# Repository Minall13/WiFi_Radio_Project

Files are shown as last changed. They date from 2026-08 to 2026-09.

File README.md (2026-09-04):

# Wi-Fi Radio Project

A standalone touchscreen Internet radio built around the ESP32-S3, with a curated UK station library, live programme metadata, custom carrier PCB and a fully 3D-printed enclosure.

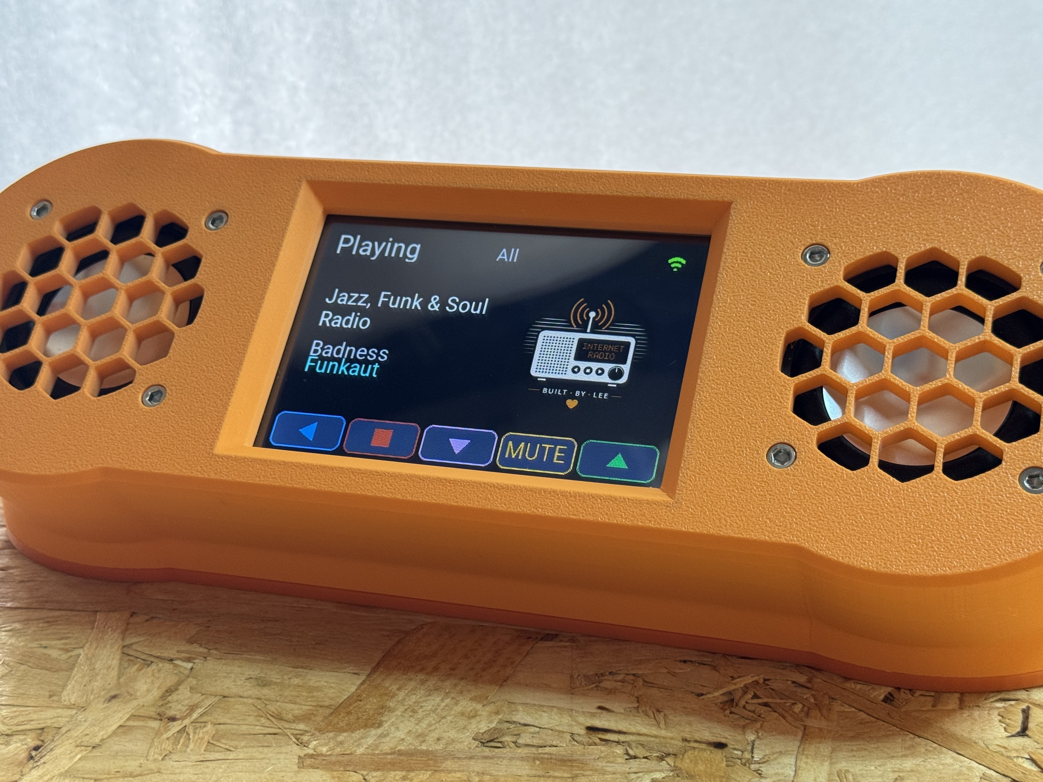
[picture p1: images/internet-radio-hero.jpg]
Wi-Fi Radio Project


The Wi-Fi Radio Project was developed from an initial ESP32 prototype into a complete self-contained radio. The hardware, firmware, user interface, station catalogue, artwork pipeline, PCB and enclosure have all been developed specifically for the project.

The finished radio is designed to behave as an appliance: switch it on, select a station and listen.

---

## Features

- 4-inch 480 × 320 colour touchscreen interface
- ESP32-S3 with 16 MB Flash and 8 MB PSRAM
- Curated UK Internet radio station library
- BBC and commercial radio support
- Live ICY track metadata
- BBC programme metadata
- Station artwork
- Dual-mono audio using two MAX98357A I²S amplifier modules
- Two 3 W / 4 Ω speakers
- Custom carrier PCB
- USB-C power and firmware programming
- Wi-Fi configuration
- Local station catalogue and artwork stored in LittleFS
- Automatic Station Library Builder
- Fully 3D-printable enclosure

---

## User Interface

The radio uses a purpose-built touchscreen interface rather than a generic ESP32 menu system.

Stations are organised into simple groups such as BBC, Absolute, Virgin, Capital, Heart, Kiss, Rock and Talk, with an **All** option providing access to the complete catalogue.

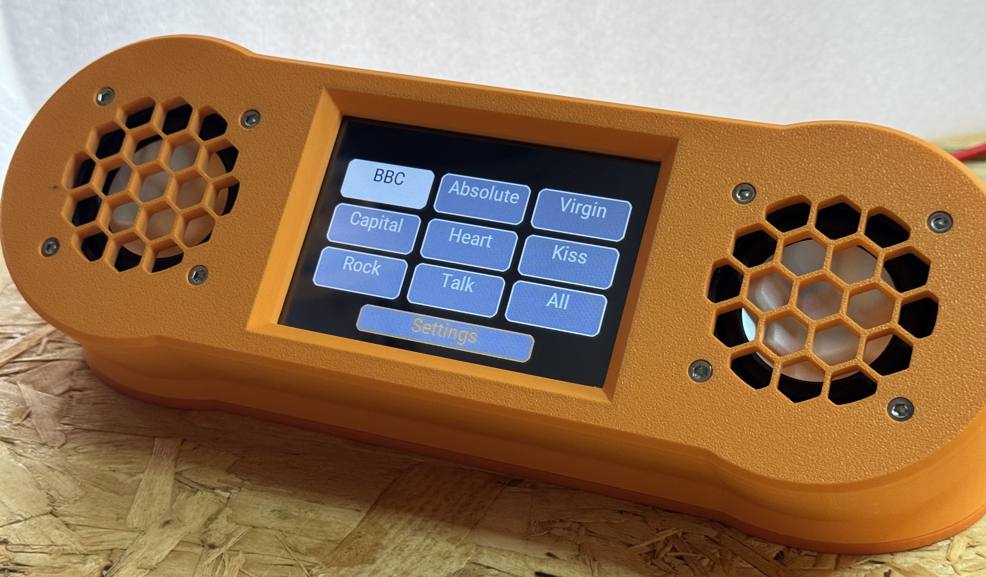
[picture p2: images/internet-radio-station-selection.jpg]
Station selection


The Player screen displays the current station, programme or track information and station artwork, together with controls for navigation, stop, volume and mute.

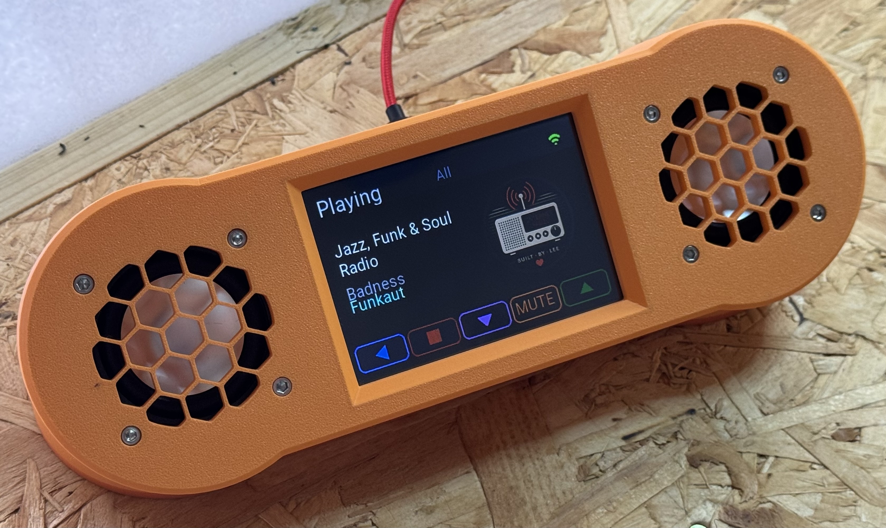
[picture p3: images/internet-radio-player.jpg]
Wi-Fi Radio Player


The startup sequence initialises the filesystem, connects to Wi-Fi, prepares BBC programme information and starts the audio subsystem before presenting the radio for use.

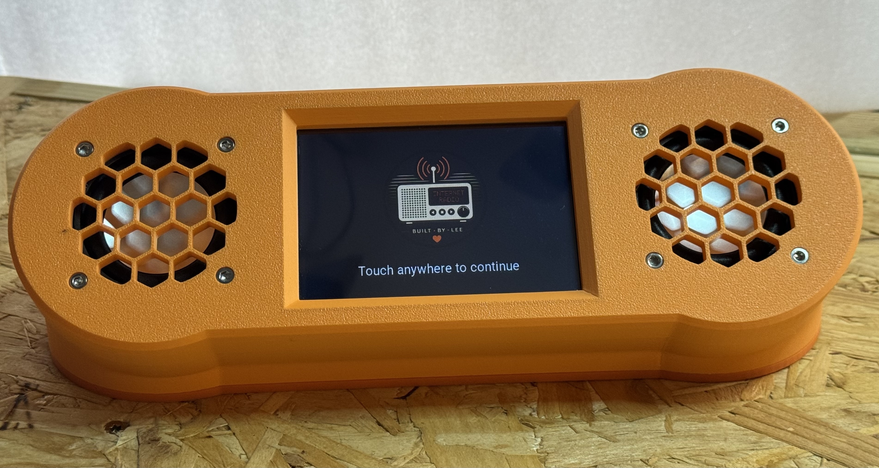
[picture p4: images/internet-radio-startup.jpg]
Wi-Fi Radio startup


---

## Hardware

### Controller

The radio is based around an **ESP32-S3 DevKitC-1 N16R8**:

- 16 MB Flash
- 8 MB PSRAM
- Wi-Fi
- Dual-core ESP32-S3 processor

### Display

- 4-inch 480×320 SPI TFT display, sold as ILI9488 and configured with TFT_eSPI using `ILI9481_DRIVER`
- XPT2046 resistive touchscreen

### Audio

Dual-mono audio is provided by:

- 2 × MAX98357A I²S Class-D amplifier modules
- 2 × 3 W / 4 Ω full-range speakers

### Carrier PCB

A custom KiCad-designed carrier PCB connects the ESP32-S3, display, audio modules, power switching and external USB-C connection.

The PCB was designed specifically for the finished radio and manufactured as part of the project.

The proven Rev A PCB can be ordered directly from the [Wi-Fi Radio Project page on PCBWay](https://www.pcbway.com/project/shareproject/Wi_Fi_Radio_Project_ESP32_S3_Main_PCB_076f3c4a.html).

The rear-panel USB-C connection provides both normal 5 V power and access to the ESP32-S3 USB interface, allowing firmware to be uploaded without dismantling the radio.

PCB design files and manufacturing Gerbers are provided in the `Hardware/` directory.

### Enclosure

The enclosure is fully 3D printed and consists of three principal components:

- Main case
- Face frame
- Base

STL files are provided in this repository for slicer-independent printing.

A Bambu Studio 3MF project, including the complete assembly and individual printable components, is available on [MakerWorld](https://makerworld.com/en/models/3243705-wi-fi-radio-project#profileId-3675408).

The files are located in:

`3D_Files/`

---

## Bill of Materials

A complete parts list for one radio is provided in:

**[BOM.md](BOM.md)**

The BOM includes quantities and example sources for the components used in the original build.

Equivalent components may be used where their electrical and mechanical specifications are compatible.

---

## Software Architecture

The firmware is divided into independent subsystems with clearly defined responsibilities.

```text
Station Library Builder
        │
        ▼
LittleFS Catalogue
        │
        ▼
Station Provider
        │
        ▼
User Interface
        │
        ▼
Player
        │
        ├───────────────┐
        ▼               ▼
Audio Engine     BBC Metadata
        │
        ▼
I²S Audio
        │
        ▼
2 × MAX98357A
```

This separation keeps the user interface, station data, metadata handling and audio playback largely independent of one another.

More detailed design information is available in the `docs/` directory.

---

## Station Library

Rather than querying an Internet radio directory every time the radio starts, the project uses a curated UK station catalogue generated offline.

The **Station Library Builder**:

- validates station definitions;
- selects preferred production streams;
- generates the station catalogues;
- obtains and prepares station artwork;
- generates default artwork where required;
- prepares the files for deployment to LittleFS.

The ESP32 therefore operates from its own local catalogue during normal use.

This makes the radio independent of a live station-directory service while it is operating.

---

## Metadata

Commercial stations primarily use **ICY metadata** supplied by their audio streams.

BBC stations are handled separately using BBC programme metadata, allowing the Player screen to display the programme currently being broadcast.

---

## Station Artwork

Station artwork is stored as PNG images in LittleFS and displayed on the Player screen.

The artwork pipeline can obtain station artwork, apply curated replacements where necessary, generate appropriately sized images and provide default artwork for stations without suitable source material.

> Station names, logos and other third-party branding remain the property of their respective owners. Third-party station artwork is not intended to imply affiliation with or endorsement of this project.

---

## Repository Structure

    WiFi_Radio_Project/
    │
    ├── 3D_Files/                       3D-printable enclosure files
    ├── Hardware/                       KiCad PCB design and manufacturing files
    ├── data/                           Station catalogue and runtime assets
    │   ├── branding/
    │   ├── catalogues/
    │   ├── fonts/
    │   ├── icons/
    │   └── logos/
    ├── docs/                           Project documentation
    ├── images/                         Documentation images
    ├── tools/                          Build and asset-generation utilities
    │   ├── Icon_Builder/
    │   └── Station_Library_Builder/
    │
    ├── WiFi_Radio_Project.ino	        Main Arduino sketch
    ├── partitions.csv                  ESP32 flash partition layout
    ├── deploy                          LittleFS deployment helper
    ├── BOM.md                          Bill of materials
    └── README.md

The remaining numbered `.ino` files in the project root contain the supporting firmware modules.

---

## Building the Radio

The repository contains the principal resources required to reproduce the project:

1. Firmware source
2. Bill of materials
3. KiCad PCB design
4. PCB manufacturing Gerbers
5. 3D-printable enclosure
6. Station Library Builder
7. Supporting documentation

The project was developed and tested using the specific hardware listed in the BOM. Substituting components may require changes to the PCB, enclosure, firmware configuration or pin assignments.

---

## Project Status

**Version 1.0.1**

The Wi-Fi Radio Project has reached its first complete hardware and software release.

The v1.0.1 system includes:

- completed touchscreen user interface;
- curated UK station library;
- streaming audio engine;
- BBC programme metadata;
- ICY metadata;
- station artwork pipeline;
- custom carrier PCB;
- USB-C power and programming;
- dual-mono amplifier and speaker system;
- finished 3D-printed enclosure.

The radio has been assembled and tested as a complete standalone unit.

---

## Documentation

Additional technical documentation is available in the [`docs/`](docs/) directory, covering subjects including:

- system architecture;
- audio;
- display;
- touchscreen;
- operation;
- station catalogue generation;
- artwork and fonts;
- hardware design;
- project history.

---

## Third-Party Components and Services

This project uses a number of third-party open-source libraries, hardware modules and Internet services.

Radio station names and trademarks belong to their respective owners.

Availability and format of Internet radio streams and external metadata services can change independently of this project.

---

## Licence

The Wi-Fi Radio Project uses a mixed licensing model.

Original project software is licensed under the **PolyForm Noncommercial License 1.0.0**.

Original hardware designs, PCB files, 3D-printable models, documentation and project photographs are licensed under the **Creative Commons Attribution-NonCommercial 4.0 International (CC BY-NC 4.0)** licence.

These licences permit personal, non-commercial use, modification and redistribution subject to their respective terms and attribution requirements. Commercial use of the original project material is not permitted without separate permission from the copyright holder.

Third-party components and assets remain subject to their own licences.

See [`LICENSE.md`](LICENSE.md) for the complete licensing details and attribution requirements.

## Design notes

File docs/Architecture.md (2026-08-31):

# Wi-Fi Radio Project — Architecture

## Overview

The Wi-Fi Radio Project firmware is organised as a modular ESP32-S3 application.

Functionality is divided across Arduino `.ino` tabs, with each tab responsible for a specific area of the system. The source files contain their own detailed header documentation; this document therefore describes the overall architecture and the relationships between the major parts of the application.

The principal design goal is to keep the user interface, station catalogue, audio playback and metadata systems independent of one another.

---

## High-Level Architecture

The application can be viewed as four main functional areas:

```text
User Interface / Touch
        │
        ▼
Station Provider
        │
        ├──────────────► Station Artwork
        │
        ▼
Audio Engine
        │
        ├──────────────► ICY Metadata
        │
        └──────────────► BBC Programme Metadata
```

Supporting modules provide Wi-Fi management, themes, typography, icons, startup behaviour and system information.

This separation allows individual parts of the radio to be changed without requiring corresponding changes throughout the application.

---

## Station Catalogue

Normal radio operation uses locally stored station catalogues held in LittleFS.

The catalogues are generated offline by the Python **Station Library Builder** and contain the information required by the firmware to present and play the curated station library.

The Station Provider acts as the interface between the user interface and these catalogue files.

This means that normal station browsing does not depend upon live access to an external station-directory service.

Only the catalogue data required at a particular time is loaded, reducing RAM usage on the ESP32-S3.

---

## Playback Model

Station browsing and station playback are deliberately treated as separate operations.

The application maintains independent state for:

- the currently selected station;
- the currently playing station;
- the current playback state.

This distinction allows the user to leave the Player screen and browse the Station List while the current station continues playing.

Consequently:

```text
Player → Back → Station List
```

preserves playback, whereas:

```text
Player → Stop → Filter Selection
```

terminates playback and returns to the beginning of the normal station-selection flow.

This behaviour is intentional and forms part of the application's navigation model.

---

## Audio

Audio streaming is handled independently by the Audio Engine.

The engine is responsible for:

- stream connection and playback;
- I²S audio output;
- volume control;
- mute state;
- playback status;
- stream metadata handling.

Audio is output through two MAX98357A I²S amplifier modules driving two speakers in a dual-mono configuration.

Keeping audio processing separate from the user interface allows playback to continue while other screens are displayed.

---

## Metadata

The project uses two separate metadata mechanisms.

### ICY Metadata

Commercial internet-radio streams may provide ICY metadata as part of the audio stream.

Where available, this information is used to display the current artist and track on the Player screen.

### BBC Programme Metadata

BBC stations use a separate metadata mechanism to obtain current programme information.

This information is handled independently from the audio stream and presented through the same Player interface.

Separating the two mechanisms allows the user interface to present consistent programme information despite the different metadata sources.

---

## Local Assets

LittleFS provides the radio's local runtime asset storage.

It contains resources including:

- station catalogues;
- station artwork;
- fonts;
- icons.

Keeping these resources locally provides predictable UI performance and avoids unnecessary network dependencies during normal navigation.

The project's custom flash partition configuration and LittleFS deployment process are documented separately in `Build_and_Deploy.md`.

---

## Design Principles

The firmware architecture follows a small number of deliberate principles:

- each module should have a clearly defined responsibility;
- UI rendering should remain separate from audio playback;
- navigation should not unnecessarily interrupt playback;
- station catalogue access should be abstracted from the UI;
- external metadata services should not control core navigation;
- runtime assets should be stored locally where practical;
- common visual behaviour should be controlled through shared theme, typography and icon systems.

The result is a firmware structure in which the major subsystems can be maintained independently while presenting a single consistent interface to the user.

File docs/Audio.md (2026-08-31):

# Wi-Fi Radio Project — Audio

## Overview

The Wi-Fi Radio Project provides Internet radio playback using the ESP32-S3, the ESP32-audioI2S library and two MAX98357A I²S amplifier modules.

The audio subsystem supports the stream formats used by the curated station library, including MP3, AAC/AAC+, HTTP, HTTPS and BBC HLS streams.

Audio processing is intentionally isolated from the user interface and station catalogue.

---

## Hardware

### Controller

ESP32-S3 N16R8

### Amplifiers

2 × MAX98357A I²S Class-D amplifier modules.

Both amplifiers receive the same I²S audio data and drive separate speakers, providing a dual-mono output.

### Speakers

2 × 3 W, 4 Ω speakers.

---

## I²S Configuration

| Signal | GPIO |
|---|---|
| BCLK | GPIO6 |
| LRCK | GPIO7 |
| DOUT | GPIO5 |

The two MAX98357A modules share the I²S signals.

The known working module configuration is:

| Pin | Connection |
|-----|---|
| VIN | 5 V |
| GND | GND |
| DIN | GPIO5 |
| BCLK | GPIO6 |
| LRC | GPIO7 |
| SD | 3.3 V |
| GAIN | Floating |

---

## Audio Library

The project uses **ESP32-audioI2S**.

The library is wrapped by the project's Audio Engine rather than being accessed directly by the user interface.

The principal interface includes:

```cpp
audioBegin()
audioPlay()
audioStop()
audioLoop()
audioSetVolume()
audioGetVolume()
```

This abstraction keeps playback implementation separate from UI and station-catalogue logic.

---

## Volume and Mute

The normal default volume is:

```text
14
```

This provides clean playback with the amplifier and speaker combination used in the finished radio.

Mute is implemented as a latching control. Muting silences the output without terminating the active stream, allowing playback to resume immediately when mute is released.

---

## DMA Configuration

An important optimisation made during development concerns the audio DMA configuration.

HTTPS connection failures were traced to **internal RAM pressure**, rather than to TLS itself.

The ESP32-audioI2S default DMA configuration allocated more internal memory than this application required.

The project therefore uses:

```cpp
audio.settings.DMA_DESC_NUM = 16;
```

rather than the library default of 32 descriptors.

This change:

- increases available internal heap;
- increases the largest available internal memory block;
- improves reliability when establishing HTTPS streams;
- leaves sufficient memory for metadata operations during playback;
- produces no observable reduction in playback quality.

This setting forms part of the project's known working audio configuration.

---

## Main Loop Requirements

The audio library requires:

```cpp
audioLoop();
```

to be serviced frequently.

Long blocking operations can result in buffer underruns, interrupted audio, slower reconnects or delayed metadata processing.

During development, a long main-loop delay was found to cause periodic audio pulsing. Reducing the delay to approximately 1 ms restored stable playback.

Code added to the main application loop should therefore avoid unnecessary blocking operations.

---

## Metadata

### Commercial Stations

Where supported by the station stream, ICY metadata provides current artist and track information.

Metadata updates are handled without requiring the complete Player screen to be redrawn.

### BBC Stations

BBC programme information is obtained separately from the audio stream through the project's BBC metadata subsystem.

This allows current BBC programme information to be presented through the Player interface even though it is supplied through a different mechanism from commercial ICY metadata.

---

## Playback Behaviour

The Audio Engine maintains playback independently from screen navigation.

This allows the current stream to continue when the user selects **Back** from the Player and returns to the Station List.

Selecting **Stop** explicitly terminates the current stream.

Volume and mute operations alter the audio output without changing the selected station or navigation state.

---

## Design Constraints

Changes to the audio subsystem should preserve the following known working characteristics:

- I²S on GPIO5, GPIO6 and GPIO7;
- dual-mono MAX98357A output;
- frequent servicing of `audioLoop()`;
- minimal blocking activity during playback;
- reduced DMA descriptor allocation;
- sufficient internal RAM for HTTPS connections and metadata operations.

These constraints were established through testing and form part of the stable v1.0 audio implementation.

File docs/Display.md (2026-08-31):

# Display Hardware Notes

## Hardware

Display: 4" SPI TFT Touch Display

Touch Controller: XPT2046

Controller advertised by seller: ILI9488

Board used: ESP32-S3 N16R8

---

## TFT_eSPI Configuration

Working TFT_eSPI setup:

```cpp
#define USE_HSPI_PORT

#define ILI9481_DRIVER

#define TFT_MISO 13
#define TFT_MOSI 11
#define TFT_SCLK 12
#define TFT_CS   10
#define TFT_DC    9
#define TFT_RST   8
```

---

## Important Discovery

Although the display was advertised and silk-screened as an ILI9488 display, it would not operate correctly using:

```cpp
#define ILI9488_DRIVER
```

The display only operated correctly when configured as:

```cpp
#define ILI9481_DRIVER
```

This should be considered the known-good configuration for this display module.

---

## Touchscreen Discovery

For the XPT2046 touchscreen to function correctly:

```text
TFT SDO (MISO) must be disconnected
```

Working touch wiring:

```text
T_DO  -> GPIO13
T_DIN -> GPIO11
T_CLK -> GPIO12
T_CS  -> GPIO14
T_IRQ -> Not connected
```

If TFT SDO remains connected to GPIO13, the touchscreen reports:

```text
Touched = YES | X = 0 | Y = 0 | Z = 4095
```

continuously and does not respond to touch input.

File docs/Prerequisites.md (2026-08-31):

# Prerequisites

This document describes the software and development tools required to build, deploy, inspect and modify the Wi-Fi Radio Project.

Not every tool listed here is required for every task. The minimum requirements depend on whether you are:

- building and uploading the firmware;
- rebuilding the station catalogue and artwork;
- regenerating display fonts;
- modifying the PCB;
- modifying or printing the enclosure.

---

## 1. Arduino Development

### Arduino IDE

The firmware is developed and uploaded using **Arduino IDE**.

Install the current Arduino IDE from the official Arduino website.

### ESP32 Board Support

Install the **ESP32 Arduino board package** through Arduino IDE.

The project hardware uses an:

**ESP32-S3 DevKitC-1 N16R8**

with:

- 16 MB Flash;
- 8 MB PSRAM.

When compiling the project, ensure that the selected board and Flash/PSRAM settings are appropriate for the N16R8 module.

The project also uses the custom root-level `partitions.csv`, which provides approximately:

- 3 MB application space;
- 12.9 MB LittleFS space;
- no OTA application partition.

Further build and upload instructions are provided in `docs/Build_and_Deploy.md`.

---

## 2. Arduino Libraries

The finished firmware uses the following libraries:

- ArduinoJson
- ESP32-audioI2S (`Audio.h`)
- HTTPClient
- LittleFS
- PNGdec
- TFT_eSPI
- WiFi
- WiFiClientSecure
- WiFiManager
- XPT2046_Touchscreen

The following are provided as part of the ESP32 Arduino environment rather than installed as separate third-party libraries:

- SPI
- WiFi
- WiFiClientSecure
- HTTPClient
- LittleFS
- `esp_heap_caps.h`

Where a library version is important to project behaviour, use the version documented with the project.

The audio implementation was developed and validated using:

**ESP32-audioI2S 3.4.6**

---

## 3. Python

The Station Library Builder is written in Python.

Install a current **Python 3** release.

The Station Library Builder requires the Pillow Python package. It must be installed in the project's virtual environment before any Station Library Builder command can be run.

The recommended project setup is to use a Python virtual environment in the repository root.

Create the environment with:

`python3 -m venv .venv`

Activate it on macOS or Linux with:

`source .venv/bin/activate`

The Station Library Builder uses Python standard-library modules together with one external package:

**Pillow**

Install Pillow with:

`python -m pip install Pillow`

The Station Library Builder can then be run using:

`./.venv/bin/python tools/Station_Library_Builder/station_catalogue_manager.py build`

Detailed station catalogue and artwork information is provided in `docs/Station_Artwork.md`.

---

## 4. Processing IDE

The display uses TFT_eSPI Smooth Fonts stored as `.vlw` files.

To regenerate or modify these fonts, install:

**Processing IDE**

The font-generation workflow uses the TFT_eSPI Smooth Font generator, normally based on `Create_font.pde`.

The project uses the Google Roboto SemiCondensed font family.

The current generated font assets are stored in `data/fonts/`.

Detailed font-generation information is provided in `docs/FontGeneration.md`.

Processing is not required merely to compile or upload the existing firmware if the supplied `.vlw` files are retained.

---

## 5. Source-Code Editor

A separate source-code editor is optional.

The project can be edited entirely using Arduino IDE, but a general-purpose editor may be more convenient for:

- Python;
- JSON;
- Markdown documentation;
- repository-wide searches;
- project maintenance.

The project was developed using tools including **Visual Studio Code** and **BBEdit**, but neither is a mandatory dependency.

---

## 6. Git

Git is recommended when cloning or maintaining the project repository.

Typical uses include:

- downloading the source;
- tracking local modifications;
- updating from GitHub;
- maintaining personal branches or forks.

Git is not required simply to copy the source files and build the project manually.

---

## 7. KiCad

The custom carrier PCB was designed using:

**KiCad 10**

Install KiCad if you want to:

- inspect the schematic;
- inspect or modify the PCB;
- regenerate manufacturing files;
- create a revised board design.

The authoritative hardware design files are stored in `Hardware/`.

KiCad is not required to build firmware for an already assembled radio.

---

## 8. 3D Printing and CAD

The enclosure consists of three printable components:

- Base;
- Main Case;
- Face Frame.

Generic STL files are provided for use with compatible slicers and printers.

The supported Bambu-oriented print package is published separately through MakerWorld.

For Bambu printers, **Bambu Studio** or the Bambu Handy / MakerWorld workflow can be used.

Other slicers may be used with the supplied STL files.

A CAD application is only required if the enclosure geometry is to be modified.

---

## 9. USB Connection

Firmware can be uploaded directly to the ESP32-S3 through USB.

The finished radio provides rear USB-C access so firmware can be updated without disassembling the enclosure.

Before uploading firmware or LittleFS data:

- close Arduino Serial Monitor;
- close any other application using the ESP32 USB/serial port;
- confirm the correct USB device is selected.

---

## 10. Minimum Setup by Task

### Firmware only

Required:

- Arduino IDE;
- ESP32 Arduino board support;
- required Arduino libraries;
- USB connection to the ESP32-S3.

### Rebuild station catalogue and artwork

Additionally required:

- Python 3;
- Python virtual environment;
- Pillow.

### Regenerate fonts

Additionally required:

- Processing IDE;
- TFT_eSPI Smooth Font generator;
- required font family.

### Modify PCB

Additionally required:

- KiCad 10 or a compatible later version.

### Print enclosure

Required:

- suitable slicer or MakerWorld/Bambu workflow;
- compatible 3D printer.

---

## 11. Next Step

Once the required tools are installed, continue with `docs/Build_and_Deploy.md`.

For station catalogue and artwork preparation, see `docs/Station_Artwork.md`.

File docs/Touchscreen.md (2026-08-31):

# Touchscreen Hardware Notes

## Hardware

Touch Controller: XPT2046

Display Module: 4" SPI TFT Touch Display

Processor: ESP32-S3 N16R8

---

## Working Wiring

| Touch Pin | ESP32-S3 Pin  |
| --- | --- |
| T_DO | GPIO13 |
| T_DIN | GPIO11 |
| T_CLK | GPIO12 |
| T_CS | GPIO14 |
| T_IRQ | Not connected |

---

## Critical Discovery

The TFT and touch controller cannot both drive GPIO13.

The TFT SDO(MISO) connection must be disconnected.

```text
TFT SDO(MISO) = Not Connected
Touch T_DO    = GPIO13
```

If TFT SDO remains connected:

```text
Touched = YES | X = 0 | Y = 0 | Z = 4095
```

is reported continuously and the touch screen does not respond.

---

## Calibration Values

```cpp
#define TOUCH_MIN_X 300
#define TOUCH_MAX_X 3820
#define TOUCH_MIN_Y 420
#define TOUCH_MAX_Y 3770
```

---

## Coordinate Mapping

Landscape orientation:

```cpp
int screenX = map(p.x, TOUCH_MIN_X, TOUCH_MAX_X, 0, 480);
int screenY = map(p.y, TOUCH_MIN_Y, TOUCH_MAX_Y, 0, 320);
```

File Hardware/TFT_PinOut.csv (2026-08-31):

ESP32-S3 |  | TFT
* |  | 1 | T_IRQ
13 | ___________ | 2 | T_DO
11 | ___________ | 3 | T_DIN
14 | ___________ | 4 | T_CS
12 | ___________ | 5 | T_CLK
* |  | 6 | SDO (MISO)
3V3 | ___________ | 7 | LED
12 | ___________ | 8 | SCK
11 | ___________ | 9 | SDI (MOSI)
9 | ___________ | 10 | DC/RS
8 | ___________ | 11 | RESET
10 | ___________ | 12 | CS
GND | ___________ | 13 | GND
3V3 | ___________ | 14 | VCC

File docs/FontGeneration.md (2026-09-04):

# Font Generation

## Purpose

This project uses TFT_eSPI Smooth Fonts (`.vlw`) to provide a clean, professional typography system for the Internet Radio user interface.

The generated font files are stored in:

```text
/data/fonts/
```

---

## Font Family

Google Roboto SemiCondensed

---

## Font Generator

The `.vlw` fonts were generated using:

- Processing IDE
- TFT_eSPI `Create_font.pde`

The TFT_eSPI font-generation utility can be found within the installed TFT_eSPI library under:

```text
Tools/Create_Smooth_Font/Create_font/
```

---

## Project Font Set

The Smooth Font files currently stored with the project are:

| File | Size |
|---|-----:|
| Roboto24.vlw | 24 pt |
| Roboto28.vlw | 28 pt |
| Roboto32.vlw | 32 pt |
| Roboto36.vlw | 36 pt |
| Roboto38.vlw | 38 pt |
| Roboto40.vlw | 40 pt |

The active typography mappings are defined in `08_UI_Typography.ino`.
`Roboto38.vlw` is retained in the font set but is not currently assigned to a UI typography role.

The font files are stored in:

```text
/data/fonts/
```

---

## Processing Settings

For each font generated:

* `fontType = ""`
* `fontSize = required size`
* `displayFontSize = same as fontSize`
* Unicode Block:

  * Basic Latin (`0x0021`–`0x007E`)
* Anti-aliased:

  * Enabled

The generated `.vlw` file is copied into:

```text
/data/fonts/
```

and renamed using the project's standard naming convention.

---

## Design Principle

Application code should never reference a specific font family.

All text rendering is performed through the Typography module (`08_UI_Typography.ino`) using semantic roles such as:

* Header
* Section
* Body
* Button
* Caption
* Status
* Display

This allows the font family, weight and point size to be changed in one location without modifying the application UI.

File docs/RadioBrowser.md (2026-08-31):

# Radio Browser

## Purpose

Radio Browser provides the source data used to build the Internet Radio station catalogue.

It is **not** used during normal operation of the radio.

Instead, the Python **Station Library Builder** processes, validates and prepares station data before generating the production catalogue stored in LittleFS.
---

## Current Workflow

```text
Radio Browser API
        │
        ▼
Station Library Builder (Python)
        │
        ▼
station_library.json
        │
        ▼
Paged catalogue files
(catalogues/*.json)
        │
        ▼
LittleFS Image
        │
        ▼
ESP32 Internet Radio
```

---

## Responsibilities

### Radio Browser

- Provides UK station metadata
- Provides stream URLs
- Provides station tags and codec information
- Provides station logos (where available)

### Wi-Fi Radio Project

- Selects supported UK stations
- Removes duplicate entries
- Builds production catalogue files
- Stores the catalogue in LittleFS
- Loads catalogue pages during runtime

---

## Runtime Behaviour

During normal operation the ESP32 **never queries Radio Browser**.

Station browsing is performed entirely from the locally stored catalogue.

This provides:

- Faster station browsing
- Reduced network traffic
- Consistent station ordering
- Offline browsing capability (network required only for audio streaming)

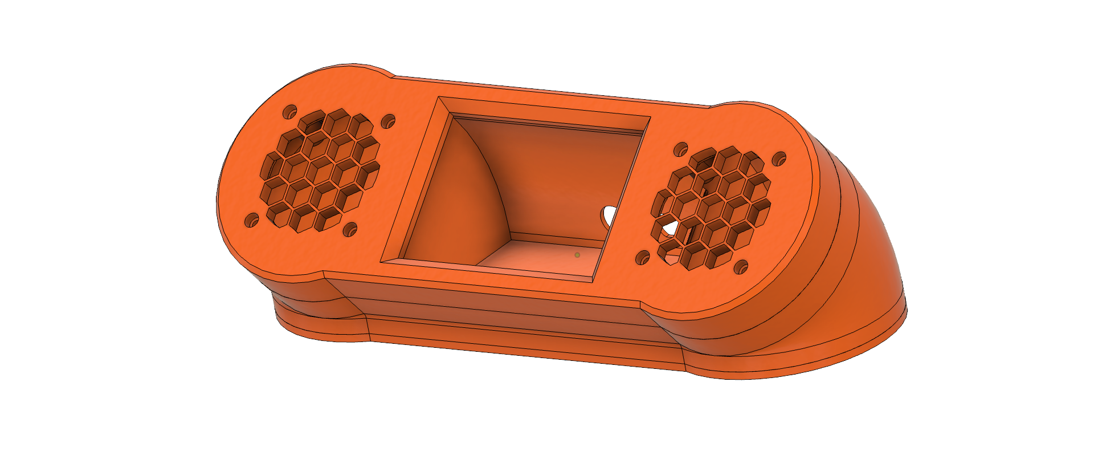
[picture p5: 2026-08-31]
3D_Files/Wi-Fi Radio Project Render.png

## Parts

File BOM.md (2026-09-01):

# Wi-Fi Radio Project — Bill of Materials

This document lists the principal components used to build the Wi-Fi Radio Project.

The links below are provided as examples of the components used in the original build. Equivalent parts may be substituted where their electrical and mechanical specifications are compatible.

> **Note:** Retail links may change or become unavailable over time. The project is not affiliated with or endorsed by the listed retailers or manufacturers.

## Main Components

| Ref | Qty | Component | Example Source |
| --- | ---: | --- | --- |
| IRP001 | 1 | ESP32-S3 DevKitC-1 N16R8 Module | [Amazon UK](https://amzn.eu/d/0hGKXkMX) |
| IRP002 | 1 | 4 inch LCD TFT touch display | [Amazon UK](https://amzn.eu/d/0cEZjH7h) |
| IRP003 | 2 | MAX98357A I²S 3 W Class-D Audio Amplifier Module | [Amazon UK](https://amzn.eu/d/02SEZ3c8) |
| IRP004 | 2 | 2" 4 Ohm 3 W Full Range Audio Speaker Stereo Woofer Loudspeaker | [Amazon UK](https://amzn.eu/d/07zwBBQc) |
| IRP005 | 1 | USB Type-C Screw Panel Mount to 6-pin JST-PH Cable | [Amazon UK](https://amzn.eu/d/0ejVC6VA) |
| IRP006 | 1 | USB-C to XH2.54 4-pin Terminal Motherboard Power Supply Cable | [Amazon UK](https://amzn.eu/d/01NWOgeu) |
| IRP007 | 1 | Ultra Slim Flat USB-C Type-C Male to Female Extension Data Cable, 90° | [Amazon UK](https://amzn.eu/d/021Mz2hg) |
| IRP008 | 1 | Push Button SPST Latching Switch | [Amazon UK](https://amzn.eu/d/03VBz3cK) |
| IRP009 | 4 | M3 (3 mm × 20 mm) Allen Socket Cap Head Screws | [Amazon UK](https://amzn.eu/d/0aBU8Lml) |
| IRP010 | 8 | M3 (3 mm × 10 mm) Allen Socket Cap Head Screws | [Amazon UK](https://amzn.eu/d/0j475W6z) |
| IRP011 | 12 | M3 Threaded Inserts | [Amazon UK](https://amzn.eu/d/0cYBCU3H) |

## Notes

- Check component dimensions and pinouts before ordering substitutes.
- The PCB and enclosure were designed around the components used in the original build, so mechanically different alternatives may require modification.
- Quantities shown are for one complete Wi-Fi Radio Project unit.

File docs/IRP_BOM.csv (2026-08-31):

Part No. | Quantity | Item | Item Link (Amazon)
IRP001 | 1 | ESP32-S3 DevKitC-1 N16R8 Module | https://amzn.eu/d/0hGKXkMX
IRP002 | 1 | 4 inch LCD TFT touch display | https://amzn.eu/d/0cEZjH7h
IRP003 | 2 | MAX98357 Class D Audio Amplifier Board I2S 3W DAC Decoder Breakout Module | https://amzn.eu/d/02SEZ3c8
IRP004 | 2 | 2" 4Ohm 3W Full Range Audio Speaker Stereo Woofer Loudspeaker | https://amzn.eu/d/07zwBBQc
IRP005 | 1 | USB Type C Screw Panel Mount to 6 pin JST PH Cable | https://amzn.eu/d/0ejVC6VA
IRP006 | 1 | USB-C to XH2.54 4Pin Terminal Motherboard Power Supply Cable | https://amzn.eu/d/01NWOgeu
IRP007 | 1 | Ultra Slim Flat USB-C Type-C Male to Female Extension Data Cable 90 Deg. | https://amzn.eu/d/021Mz2hg
IRP008 | 1 | Push Button SPST Latching Switch | https://amzn.eu/d/03VBz3cK
IRP009 | 4 | M3 (3mm x 20mm) Allen Socket Cap Head Screws (x4) | https://amzn.eu/d/0aBU8Lml
IRP010 | 8 | M3 (3mm x 10mm) Allen Socket Cap Head Screws (x8) | https://amzn.eu/d/0j475W6z
IRP011 | 12 | M3 Threaded Insert (x12) | https://amzn.eu/d/0cYBCU3H

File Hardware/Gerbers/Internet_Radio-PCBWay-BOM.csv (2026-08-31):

Designator | Quantity | Value | Manufacturer Part Number | Description | Package | Substitution
J2 | 1 | USB PANEL | B6B-PH-K-S | 6-pin vertical JST-PH connector, 2.00 mm pitch | JST PH 1x06 Vertical | Compatible equivalent permitted; identical pin count, pitch and PCB footprint required
J4 | 1 | USB ESP32 | B4B-XH-A | 4-pin vertical JST-XH connector, 2.50 mm pitch | JST XH 1x04 Vertical | Compatible equivalent permitted; identical pin count, pitch and PCB footprint required
J5 | 1 | POWER SW | B2B-XH-A | 2-pin vertical JST-XH connector, 2.50 mm pitch | JST XH 1x02 Vertical | Compatible equivalent permitted; identical pin count, pitch and PCB footprint required
R1 R2 | 2 | 5.1k | Generic | 5.1 kOhm resistor, 1% | 0603 (1608 metric) | Any reputable equivalent permitted

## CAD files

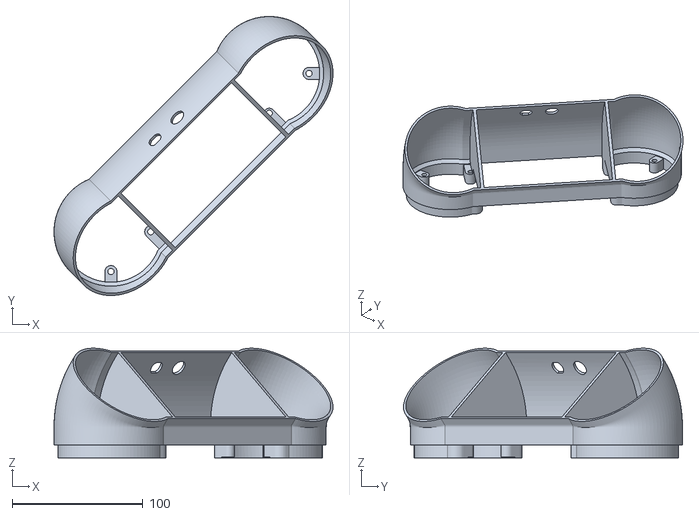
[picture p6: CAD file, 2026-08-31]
3D_Files/WRP_Main_Case.stl
213.1 x 213.1 x 83.7

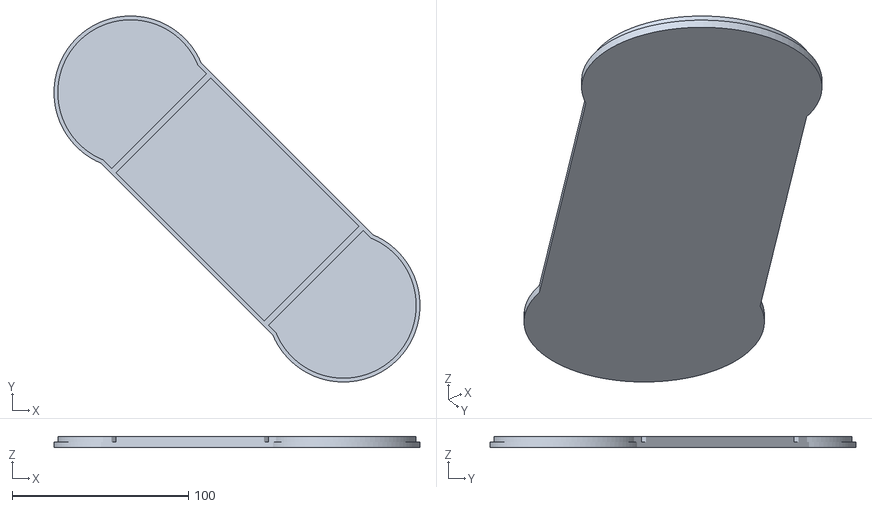
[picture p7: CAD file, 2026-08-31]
3D_Files/WRP_Base.stl
207.9 x 207.9 x 6.00

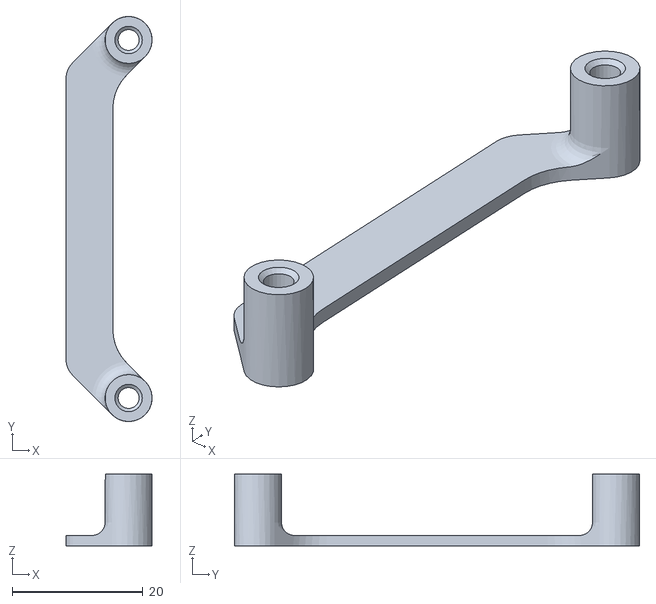
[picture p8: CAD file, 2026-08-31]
3D_Files/WRP_PCB_Stand_Off.stl
13.2 x 62.0 x 11.0

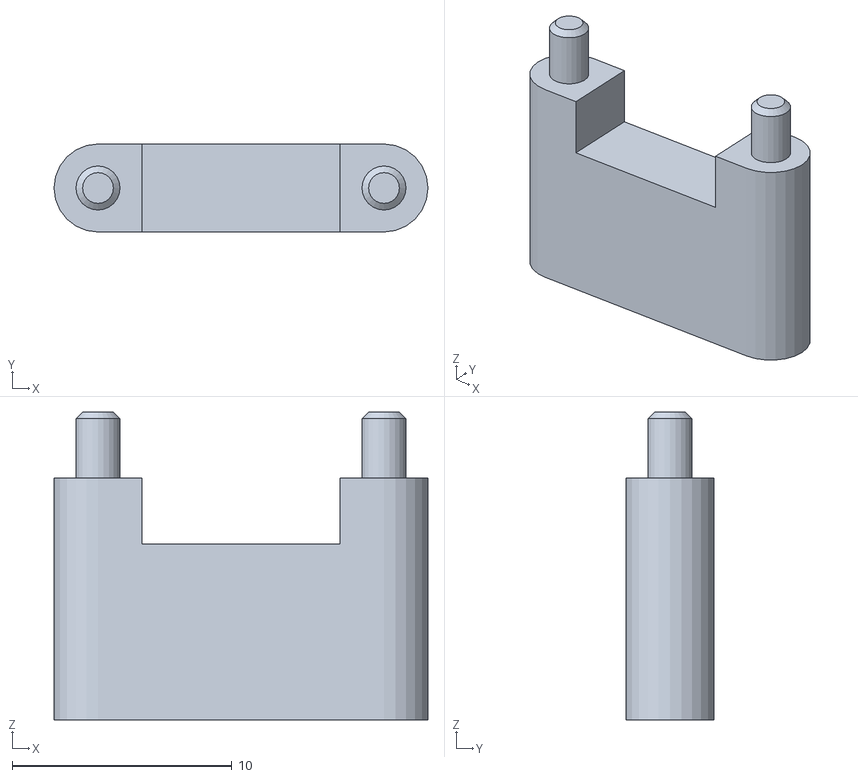
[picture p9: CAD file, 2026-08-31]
3D_Files/WRP_MAX98357A_Stand_Off.stl
17.0 x 4.00 x 14.0

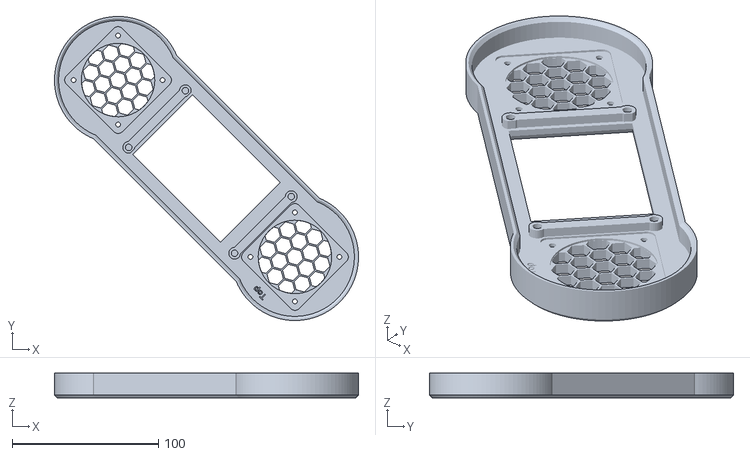
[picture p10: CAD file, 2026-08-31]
3D_Files/WRP_Face_Frame.stl
207.9 x 207.9 x 17.0

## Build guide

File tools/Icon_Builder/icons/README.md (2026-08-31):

# UI Icon Sources

The SVG files in this directory are derived from Google's Material Symbols collection and are used to generate the RAW565 status icons displayed by the Wi-Fi Radio Project.

The project currently uses the following Material Symbols:

- Wi-Fi
- Wi-Fi Off
- Bookmark Stacks
- Import Contacts
- Router
- Router Off

Material Symbols are provided by Google under the Apache License, Version 2.0.

Source:
https://fonts.google.com/icons

Project repository:
https://github.com/google/material-design-icons

Licence:
https://www.apache.org/licenses/LICENSE-2.0

The generated RAW565 files used by the radio are stored in `data/icons/`.

Google and Material Symbols are trademarks or resources of their respective owners. Their inclusion in this project does not imply endorsement of the Wi-Fi Radio Project by Google.

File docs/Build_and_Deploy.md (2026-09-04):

# Internet Radio Project — Build and Deploy

This document describes how to prepare the software, generate the station catalogue, deploy the LittleFS filesystem and upload the firmware to an Internet Radio Project unit.

It assumes that the hardware has already been assembled and that the repository has been downloaded or cloned to the development computer.

---

## 1. Requirements

### Hardware

The original project uses:

- ESP32-S3 DevKitC-1 N16R8;
- 4-inch 480 × 320 TFT display (ILI9488-labelled module, operated using the TFT_eSPI ILI9481 driver);
- XPT2046 resistive touchscreen;
- 2 × MAX98357A I²S amplifier modules;
- 2 × 3 W / 4 Ω speakers;
- Internet Radio Project carrier PCB.

See [`../BOM.md`](../BOM.md) for the complete bill of materials.

### Development Software

The build environment requires:

- Arduino IDE;
- ESP32 Arduino board package;
- Python 3;
- Python packages required by the Station Library Builder;
- `esptool`;
- the Arduino libraries used by the project.

The repository contains the project-specific tools required to build the station catalogue and LittleFS filesystem.

---

## 2. Obtain the Project

Clone or download the repository and open a Terminal in the project root.

The following files and directories should be visible:

```text
WiFi_Radio_Project.ino
data/
docs/
Hardware/
tools/
```

Commands in this document assume that the current Terminal directory is the project root.

Confirm this with:

```bash
pwd
```

---

## 3. Python Environment

The Station Library Builder is written in Python.

The development project uses a virtual environment named:

```text
.venv
```

If an appropriate virtual environment has already been created, the builder can be invoked directly using its Python interpreter:

```bash
./.venv/bin/python tools/Station_Library_Builder/station_catalogue_manager.py
```

Python environment requirements may vary according to platform and local installation.

---

## 4. Station Library Builder

The radio does not query an Internet radio directory during normal operation.

Instead, its station catalogue is prepared offline using the **Station Library Builder**.

From the project root, run:

```bash
./.venv/bin/python tools/Station_Library_Builder/station_catalogue_manager.py build
```

The builder prepares the runtime station data required by the ESP32.

Its tasks include:

1. Loading the source station information.
2. Applying the curated station definitions.
3. Preparing BBC station records.
4. Validating station information.
5. Preparing station artwork where available.
6. Generating filter catalogues.
7. Writing the station library.
8. Preparing the generated files for LittleFS deployment.

Warnings relating to unavailable external artwork do not necessarily indicate that the catalogue build has failed.

A successful build should finish with:

```text
✓ Ready for LittleFS upload.
```

---

## 5. Generated Catalogue Files

Generated runtime files are written beneath:

```text
data/
```

Important files include:

```text
data/station_library.json
data/catalogues/index.json
```

The catalogue directory can be inspected with:

```bash
ls -lh data/catalogues
```

The station catalogue is subsequently stored in the ESP32's LittleFS filesystem.

---

## 6. Station Artwork

The Station Library Builder also prepares artwork used by the Player interface.

Generated artwork is stored in the project's LittleFS data structure and is deployed with the station catalogue.

Station names, trademarks and logos remain the property of their respective owners.

A public distribution of this project may omit third-party station artwork. In that case, artwork should be obtained or generated locally using the Station Library Builder where appropriate.

---

## 7. UI Icon Generation

The Settings screen uses a small set of RAW565 status icons stored in the LittleFS filesystem.

The runtime icons used by the firmware are located in:

    data/icons/

These files can be regenerated from the source SVG artwork using the Processing-based Icon Builder supplied with the project:

    tools/Icon_Builder/

The important source files are:

    tools/Icon_Builder/SVG_to_RAW565.pde
    tools/Icon_Builder/icons/

Open `SVG_to_RAW565.pde` in the Processing IDE and run the sketch to generate the RAW565 icon variants.

Generated files are written to:

    tools/Icon_Builder/output/

The `output/` directory is generated locally and is not required to be stored in the repository.

Copy the required generated icon files into:

    data/icons/

Only the icons actually required by the firmware need to be placed there.

The files in `data/icons/` are subsequently included in the LittleFS image and uploaded to the ESP32-S3 with the rest of the runtime data.

UI icons only need to be regenerated when the icon artwork, size, colour or other graphical properties are changed.

---

## 8. Build LittleFS

The project includes a convenience helper for building and uploading the LittleFS filesystem.

Before starting, close Arduino Serial Monitor and any other application using the ESP32-S3 serial/USB connection.

From the project root, run:

    ./deploy

The root `deploy` helper invokes:

    tools/deploy_littlefs.sh

which performs the LittleFS build and upload process.

The underlying scripts are:

    tools/build_littlefs.sh
    tools/upload_littlefs.sh

The build process creates:

    build/littlefs.bin

The upload process then writes the filesystem image to the ESP32-S3 using `esptool`.

Successful deployment should finish with:

    LittleFS upload complete.

---

## 9. Script Permissions

On macOS or another Unix-like system, the deployment scripts must be executable.

If the shell reports:

```text
permission denied
```

run:

```bash
chmod +x tools/deploy_littlefs.sh \
  tools/build_littlefs.sh \
  tools/upload_littlefs.sh
```

Then retry:

```bash
./tools/deploy_littlefs.sh
```

---

## 10. USB Connection

The finished Internet Radio Project provides external USB-C access to the ESP32-S3.

This connection supports:

- 5 V power;
- USB data;
- firmware programming.

The completed radio can therefore be programmed without dismantling the enclosure.

During development, ensure that no other application is holding the ESP32 USB/serial port open.

---

## 11. Upload the Firmware

Open:

```text
WiFi_Radio_Project.ino
```

in Arduino IDE.

Confirm that:

1. The ESP32-S3 board support package is installed.
2. The correct ESP32-S3 board is selected.
3. The appropriate Flash and PSRAM settings are selected for the N16R8 module.
4. The project uses the custom `partitions.csv` supplied in the repository root. This provides a 3 MB application partition and approximately 12.9 MB for LittleFS.
5. The radio's USB port is selected under **Tools → Port**.

Click **Upload**.

Wait for Arduino IDE to report successful completion.

LittleFS and firmware are separate uploads. Uploading firmware does not normally require rebuilding the station catalogue unless its data has changed.

---

## 12. First Startup

After both LittleFS and firmware have been deployed, reset or power-cycle the radio.

The startup sequence should initialise:

```text
LittleFS
   ↓
Station data
   ↓
Wi-Fi
   ↓
BBC programme cache
   ↓
Audio
   ↓
Touch interface
```

The display reports startup progress.

When initialisation has completed, the radio displays:

```text
Ready
```

followed by:

```text
Touch anywhere to continue
```

---

## 13. Wi-Fi Provisioning

The radio requires a 2.4 GHz Wi-Fi connection.

Saved Wi-Fi credentials are reused automatically.

On a newly programmed ESP32-S3, or when valid credentials are unavailable, use the radio's Wi-Fi provisioning mechanism to select the required network and provide its credentials.

After successful provisioning, the credentials are stored by the ESP32 and normal startup should reconnect automatically.

---

## 14. Functional Test

After deployment, perform a basic functional test.

Confirm that:

1. The startup sequence completes.
2. Wi-Fi connects successfully.
3. Touching the startup screen opens the Filter screen.
4. Station filters open correctly.
5. Station lists display correctly.
6. A BBC station can be selected.
7. BBC programme information appears where available.
8. Audio plays correctly.
9. A commercial station can be selected.
10. ICY metadata appears where supplied by the broadcaster.
11. Station artwork displays correctly.

On the Player screen test:

- **Back**
- **Stop**
- **Volume −**
- **MUTE**
- **Volume +**

Expected navigation behaviour:

```text
Back → Station List
       Audio continues

Stop → Filter
       Audio stops
```

---

## 15. Serial Diagnostics

For development and troubleshooting, Arduino Serial Monitor can be used to observe the radio during startup and playback.

Useful checks include:

- LittleFS mounts successfully;
- catalogue index loads successfully;
- station catalogue pages load correctly;
- Wi-Fi connects;
- BBC metadata caching completes;
- audio initialises;
- selected streams connect;
- no unexpected ESP32 errors are reported.

Close Serial Monitor before attempting another LittleFS upload if it prevents access to the USB port.

---

## 16. Rebuilding the Station Catalogue

Rebuild the catalogue whenever station definitions, stream URLs, filters or artwork sources are changed.

From the project root:

```bash
./.venv/bin/python tools/Station_Library_Builder/station_catalogue_manager.py build
```

Then redeploy LittleFS:

```bash
./tools/deploy_littlefs.sh
```

Restart the radio after deployment.

Firmware does not need to be recompiled solely because catalogue data has changed.

---

## 17. Combined Catalogue and LittleFS Deployment

On a development system using the project's `.venv`, the catalogue build and LittleFS deployment can be chained:

```bash
./.venv/bin/python tools/Station_Library_Builder/station_catalogue_manager.py build && \
./tools/deploy_littlefs.sh
```

The LittleFS deployment will only begin if the Station Library Builder exits successfully.

Firmware upload remains a separate Arduino IDE operation.

---

## 18. Troubleshooting

### LittleFS upload cannot access the ESP32

Close:

- Arduino Serial Monitor;
- other serial terminals;
- applications using the ESP32 USB port.

Then retry the deployment.

### Station does not play

Internet radio stream URLs can change without notice.

Check whether the broadcaster has changed:

- stream URL;
- streaming protocol;
- codec;
- geographic availability.

Update the curated station definition and rebuild the catalogue if necessary.

### Artwork cannot be obtained

Artwork sources can also change or disappear.

The Station Library Builder can use alternative or default artwork where a suitable station image is unavailable.

### Wi-Fi does not connect

If stored credentials are no longer valid, repeat Wi-Fi provisioning using the required network.

---

## 19. Deployment Summary

The complete software deployment process is:

```text
Prepare development environment
          ↓
Build station catalogue
          ↓
Build LittleFS image
          ↓
Upload LittleFS
          ↓
Compile firmware
          ↓
Upload firmware
          ↓
Configure Wi-Fi if required
          ↓
Functional test
```

Once deployment and Wi-Fi configuration are complete, the radio operates as a standalone appliance and does not require the development computer for normal use.

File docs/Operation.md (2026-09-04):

# Wi-Fi Radio Project — Operation

This document describes normal operation of the completed Wi-Fi Radio Project.

The radio is designed to behave as a standalone appliance. Once firmware, station data and Wi-Fi credentials have been configured, no computer or external application is required for normal use.

---

## 1. Powering On

Press the rear power button to switch on the radio.

The startup screen displays progress while the radio initialises its main subsystems.

The normal startup sequence includes:

1. Initialising the local filesystem.
2. Connecting to Wi-Fi.
3. Caching BBC programme information.
4. Initialising the audio system.
5. Loading the station catalogue.

When startup is complete, the display shows:

**Ready**

followed by:

**Touch anywhere to continue**

Touch the screen to enter the radio interface.

---

## 2. Wi-Fi

The radio requires a 2.4 GHz Wi-Fi connection for Internet radio streaming and programme metadata.

Up to three Wi-Fi networks can be stored. At startup, the radio scans for visible saved networks and attempts to connect in most-recently-used order, allowing it to move between familiar locations without requiring Wi-Fi setup each time.

If no saved network is available, the Wi-Fi configuration system opens the InternetRadio-Setup portal so that a network can be selected and its credentials entered. Newly configured networks are added to the saved list and promoted to most-recently-used status.

Once successfully configured, the radio reconnects to the saved network automatically whenever it is switched on.

---

## 3. Station Filters

After the startup screen, the normal listening flow begins at the **Filter** screen.

Stations are organised into groups to make the catalogue easier to navigate.

Available groups include station families and categories such as:

- BBC
- Absolute
- Capital
- Heart
- Kiss
- Rock
- Talk
- Virgin

An **All** option provides access to the complete station catalogue.

Touch a filter to display the stations belonging to that group.

---

## 4. Station List

The Station List displays the stations available within the selected filter.

Touch a station to begin playback.

The radio then opens the **Player** screen and attempts to connect to the selected Internet stream.

Station information and artwork are loaded from the catalogue stored locally in LittleFS.

---

## 5. Player

The Player screen is the main listening interface.

It displays:

- station name;
- station artwork;
- current track information where available;
- BBC programme information where available;
- Wi-Fi status;
- playback controls.

The footer contains five controls:

| Control | Function |
| --- | --- |
| **Back** | Returns to the Station List while the current station continues playing |
| **Stop** | Stops playback and returns to the Filter screen |
| **Volume −** | Reduces playback volume |
| **MUTE** | Toggles latching mute without stopping the stream |
| **Volume +** | Increases playback volume |

---

## 6. Back and Stop Behaviour

**Back** and **Stop** intentionally perform different functions.

### Back

Touching **Back** returns to the current Station List while the audio stream continues playing.

This allows another station to be selected without first stopping the current one.

While a station is playing, the radio automatically returns to the Player screen after 20 seconds without touchscreen activity. Touching the screen resets this inactivity period, allowing the Station List and other screens to be browsed for as long as required.

### Stop

Touching **Stop** ends the current audio stream and returns to the Filter screen.

The Filter screen represents the beginning of the normal listening flow:

```text
Filter
  ↓
Station List
  ↓
Player
```

---

## 7. Volume

Use **Volume −** and **Volume +** to adjust playback level.

The project firmware limits the normal volume range to values suitable for the MAX98357A amplifier modules and speakers used in the original build.

Very high digital gain levels can cause audible distortion and are intentionally avoided.

---

## 8. Mute

**MUTE** is a latching control.

When mute is enabled:

- audio output is silenced;
- the Internet stream continues;
- playback position is not intentionally interrupted.

Touch **MUTE** again to restore the previous listening state.

Mute is therefore different from **Stop**, which terminates the current stream.

---

## 9. Programme and Track Information

The radio supports two principal forms of live metadata.

### Commercial Stations

Where provided by the broadcaster, ICY metadata is extracted from the audio stream and displayed on the Player screen.

This commonly contains artist and track information.

Metadata availability and formatting are controlled by the broadcaster and therefore vary between stations.

### BBC Stations

BBC stations use programme metadata obtained separately from the audio stream.

This allows the Player screen to display the programme currently being broadcast.

---

## 10. Station Artwork

Station artwork is displayed on the Player screen where suitable artwork is available.

Artwork is stored locally in LittleFS rather than downloaded each time a station is selected.

If no suitable artwork is available, the project can use default station artwork generated by the Station Library Builder.

---

## 11. Settings / System Information

The radio includes a system information/settings screen containing information about the running unit and its network connection.

The displayed information includes the current Wi-Fi connection and firmware identification.

Long Wi-Fi SSIDs are shortened on screen to fit the fixed display layout.

---

## 12. Changing Station

There are two normal ways to change station.

### Within the same group

From the Player screen:

1. Touch **Back**.
2. The current station continues playing.
3. Select another station from the Station List.
4. The Player opens for the newly selected station.

### From another group

From the Player screen:

1. Touch **Stop**.
2. Playback ends.
3. The Filter screen opens.
4. Select another filter.
5. Select the required station.

---

## 13. Switching Off

The radio may be switched off using the rear power button.

There is no software shutdown sequence required for normal use.

---

## 14. Internet Stream Availability

Internet radio streams are operated by their respective broadcasters.

A station that previously worked may occasionally become unavailable because of:

- broadcaster maintenance;
- changes to stream URLs;
- geographic restrictions;
- changes to streaming format;
- temporary Internet or server problems.

Such changes can occur independently of the Wi-Fi Radio Project.

The local station catalogue can be rebuilt or updated when station streams change.

---

## 15. Normal Listening Flow

In everyday use, operation is intentionally simple:

```text
Power On
   ↓
Startup
   ↓
Touch to Continue
   ↓
Filter
   ↓
Station List
   ↓
Player
```

From the Player:

```text
Back → Station List
       Audio continues

Stop → Filter
       Audio stops
```

The intention is that normal listening requires no knowledge of the underlying ESP32 firmware, station catalogue or streaming architecture.

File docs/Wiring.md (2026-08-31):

# Hardware Wiring

======================================

## TFT Pin Connections

======================================

| TFT Signal | TFT Pin | ESP32-S3 Pin  | Notes |
| --- | --- | --- | --- |
| VCC | 14 | 3V3 | 3.3V supply |
| GND | 13 | GND | Ground |
| CS | 12 | GPIO10 | TFT Chip Select |
| RESET | 11 | GPIO8 | Hardware Reset |
| DC / RS | 10 | GPIO9 | Data / Command |
| MOSI (SDI) | 9 | GPIO11 | SPI Data Out |
| SCK | 8 | GPIO12 | SPI Clock |
| LED | 7 | 3V3 | Backlight permanently on |
| MISO (SDO) | 6 | Not Connected | Display not read |
| T_CLK | 5 | GPIO12 | Shared SPI Clock |
| T_CS | 4 | GPIO14 | Touch CS |
| T_DIN | 3 | GPIO11 | Shared MOSI |
| T_DO | 2 | GPIO13 | Touch MISO |
| T_IRQ | 1 | Not Connected | Interrupt unused |

======================================

## MAX98357A Pin Connections

======================================

| MAX98357A | ESP32-S3 |
|---|---|
| DIN | GPIO5 |
| BCLK | GPIO6 |
| LRC | GPIO7 |
| VIN | 5V |
| GND | GND |
| SD | Floating |
| GAIN | 3.3V |

> The installed MAX98357A V914 breakout modules require `GAIN` connected
> to 3.3 V. Leaving `GAIN` floating produced no output, and mixed gain
> configurations caused severe distortion. Both amplifiers therefore use
> the same 3.3 V gain connection.

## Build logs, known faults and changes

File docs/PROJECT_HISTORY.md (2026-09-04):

# Project History

## v0.1-display-touch-working

**Date:** 19-Jun-2026

**Git Tag:** `v0.1-display-touch-working`

### Objectives Achieved

* ESP32-S3 N16R8 board verified
* 4" TFT display operational
* XPT2046 touchscreen operational
* GitHub repository established
* SSH authentication configured
* Project documentation structure created
* Prototype test sketches archived

### Key Discoveries

#### Display

Display marketed as ILI9488.

Working TFT_eSPI configuration:

```cpp
#define USE_HSPI_PORT
#define ILI9481_DRIVER
```

Display would not operate correctly using:

```cpp
#define ILI9488_DRIVER
```

#### Touchscreen

Working wiring:

```text
T_DO  -> GPIO13
T_DIN -> GPIO11
T_CLK -> GPIO12
T_CS  -> GPIO14
T_IRQ -> Not connected
```

Critical discovery:

```text
TFT SDO(MISO) disconnected
```

If TFT SDO(MISO) is connected, the touchscreen reports continuously:

```text
Touched = YES | X = 0 | Y = 0 | Z = 4095
```

### Calibration Values

```cpp
#define TOUCH_MIN_X 300
#define TOUCH_MAX_X 3820
#define TOUCH_MIN_Y 420
#define TOUCH_MAX_Y 3770
```

### Test Sketches Archived

* 01_TFT_Colour_Test
* 02_Touch_Raw_Test
* 03_Touch_Calibration_Test

### Status

PASS — Display and touchscreen operational and documented.

---

## v0.2-touch-ui-input-working

**Date:** 20-Jun-2026

**Git Tag:** `v0.2-touch-ui-input-working`

### Objectives Achieved

* Touch coordinate mapping verified
* Stations button detection working
* Settings button detection working
* Repeated touch presses working
* Serial feedback operational

### Results

Verified:

* Touch detection
* Coordinate mapping
* Button hit detection
* Repeated touch presses
* Serial feedback

### Test Sketch Archived

* 04_Touch_UI_Input_Test

### Status

PASS — Touch UI input framework operational.

---

## v0.2.1-touch-ui-display-feedback

**Date:** 20-Jun-2026

**Git Tag:** `v0.2.1-touch-ui-display-feedback`

### Objective

Resolve TFT redraw after touch events whilst maintaining reliable touch input.

### Status

PASS — TFT redraw and touch input operate reliably together.

---

## v0.3.0-wifi-connected-basic

**Date:** 21-Jun-2026

### Status

PASS — Basic Wi‑Fi connectivity operational.

---

## v0.3.1-wifi-manager-portal

**Date:** 21-Jun-2026

### Status

PASS — Complete Wi‑Fi configuration workflow operational.

---

## v0.4-radio-browser-browser-ui

**Date:** 23–24 Jun 2026

### Objectives Achieved

* Radio Browser API integrated
* API server failover implemented
* Live station retrieval verified
* TFT station browser implemented
* Touchscreen page navigation implemented
* Filter-based station browsing implemented
* Station name and stream URL storage implemented
* Screen architecture framework implemented
* Footer station selector framework implemented
* Station visual state framework implemented

### Results

Verified:

* Successful retrieval of UK radio station data from Radio Browser
* API failover between multiple Radio Browser servers
* Storage and display of station names and stream URLs
* Storage of up to 40 stations
* TFT station browser display
* Touchscreen navigation using graphical ▲ and ▼ buttons
* 5 stations per page layout adopted
* Multi-page station browsing with wrap-around navigation
* Direct filter selection screen implemented

### Screen Architecture

Display divided into fixed zones:

```text
Header   50px
Content 190px
Footer   80px
```

This architecture will be retained for all future screens.

### Footer Navigation Framework

Introduced persistent footer layout:

```text
Home  [1] [2] [3] [4] [5]  Settings
```

Design objectives:

* Large touch targets
* No precision text tapping
* Consistent navigation across all screens
* Appliance-style operation

### Station Selection Philosophy

Station lists are numbered locally per page:

Example:

```text
1. Capital Chill
2. Capital Dance
3. Capital FM Birmingham
4. Capital FM AAC
5. Capital XTRA
```

Footer buttons remain:

```text
[1] [2] [3] [4] [5]
```

Page number provides position within the overall result set.

### Button Visual States

Implemented framework for:

#### Available

* Blue outline
* Blue numeral

Current colour:

```cpp
tft.color565(0,90,220)
```

#### Selected

* Green outline
* Green numeral
* Green glow effect

Current implementation uses a simple circular glow.

#### Disabled

* Grey outline
* Grey numeral

Used for unavailable station slots on short final pages.

### Radio Browser Reliability

Observed behaviour:

* Radio Browser servers occasionally return:

  * HTTP -11
  * HTTP -1
  * HTTP 502

API failover successfully recovers by attempting alternative servers.

Future UI versions should present loading and retry progress visually rather than relying on serial output.

### User Interface Direction

Reference UI concept documented in:

```text
docs/UI_Concept_v1.md
images/Internet_Radio_UI_Concept_v1.png
```

Key design goals:

* Clean appliance-style interface
* Persistent navigation
* Consistent visual language
* Large touch targets
* Future anti-aliased typography
* Future Now Playing screen

### Status

PASS — Radio Browser integration validated.

PASS — Station browser architecture established.

PASS — UI framework established.

Audio playback integration can now proceed on a stable foundation.

---

## v0.4.10-footer-selection-logic

**Date:** 26-Jun-2026

**Git Branch:** `v0.4.10-footer-selection-logic`

### Objectives Achieved

* Footer buttons 1–5 now select visible station entries
* Selected station is tracked using `selectedStationIndex`
* Selected footer button remains green
* Previous selected button returns to blue
* Unused station buttons are disabled on short final pages
* Legacy row-touch station selection removed
* Player screen introduced using `SCREEN_PLAYER`
* Station metadata model expanded
* Radio Browser metadata captured and printed for analysis
* Project refactored into multiple Arduino `.ino` tabs
* Project documentation reorganised into `docs/`
* Hardware notes moved into `Hardware/`
* Architecture documentation created

### Station Metadata Added

The `Station` structure now stores:

```cpp
name
streamUrl
resolvedUrl
homepage
favicon
tags
codec
bitrate
isHLS
```

### Screen Architecture

The project now uses a modular screen structure:

```text
Header  = status/context
Content = current task
Footer  = navigation
```

### Arduino Tab Structure

```text
Internet_Radio_Project.ino
01_Debug.ino
02_Display_UI.ino
03_Touch_Input.ino
04_WiFi_Manager.ino
05_RadioBrowser.ino
06_BBC_Stations.ino
07_Player.ino
08_StationProvider.ino
09_UI_Theme_Design.ino
```

### Status

PASS — Footer station selection working.

PASS — Player screen introduced.

PASS — Station metadata storage working.

PASS — Project refactored into maintainable Arduino tabs.

---

## v0.5.0-ui-design-system

**Date:** 27-Jun-2026

**Git Tag:** `v0.5.0`

### Objectives Achieved

* Dynamic Header architecture completed
* Header API (`setHeader()`) implemented
* Header standardised as:

  * Left = Context
  * Centre = State
  * Right = Status
* Filter Grid established as the application landing screen
* Station List and Player screens migrated to the new Header architecture
* Wi-Fi placeholder icon introduced
* First UI Theme framework implemented
* Six colour themes created
* ThemeID framework introduced
* Central Design Guide documented
* Icons module created
* Typography module created
* Project design philosophy documented

### Design System

The project now separates visual design into dedicated modules:

```text
09_UI_Theme_Design.ino
10_UI_Icons.ino
11_UI_Typography.ino
```

This establishes a reusable design system independent of the application logic.

### UI Philosophy

The project now follows the principles:

* Premium appliance, not Arduino demo.
* Typography before decoration.
* Consistent visual hierarchy.
* Header displays context only.
* Footer provides navigation only.
* Content performs the current task.
* Information appears only when it adds value.

### Status

PASS — UI Design System established.

PASS — Theme framework operational.

PASS — Project architecture prepared for production-quality typography and iconography.

## v0.7.0 – UI Polish

### Typography

* [x] Roboto typography system
* [x] Typography roles
* [x] Smooth font integration
* [x] Standard button typography

### Icons and Graphics

* [x] SVG to RAW565 asset pipeline
* [x] Dynamic Wi-Fi icons
* [x] Shared icon framework
* [x] LittleFS icon assets

### User Interface

* [x] Home Dashboard
* [x] Filter screen
* [x] Station List
* [x] Shared header framework
* [x] Theme integration
* [x] Design consistency framework

---

## v0.8.0 – Audio Engine

* [x] MAX98357A I²S amplifier integration
* [x] Reliable audio playback
* [x] Audio abstraction layer
* [x] Playback state management
* [x] Volume control
* [x] Stream recovery
* [x] BBC HLS playback
* [x] Commercial stream playback

---

## v0.8.x – Station Library

### Catalogue Architecture

* [x] Custom ESP32 partition layout
* [x] LittleFS catalogue storage
* [x] Local Station Provider
* [x] Flat paged catalogue format
* [x] Catalogue metadata
* [x] Station Provider abstraction
* [x] Local catalogue browsing

### Station Library Builder

* [x] Curated UK station library
* [x] Production catalogue generation
* [x] Automatic LittleFS deployment
* [x] Build validation
* [x] BBC catalogue provider
* [x] Runtime Radio Browser dependency removed

---

## v0.9.0 – Player Experience

* [x] Dedicated Player footer
* [x] Station artwork
* [x] Default artwork fallback
* [x] PNG artwork pipeline
* [x] Curated artwork overrides
* [x] Rounded station artwork
* [x] Live ICY metadata
* [x] Dynamic metadata updates
* [x] Theme-aware Player typography
* [x] Metadata word wrapping
* [x] Fast station switching

---

## v0.9.1 – Initial BBC Metadata

* [x] Official BBC metadata integration
* [x] BBC RMS metadata client
* [x] National BBC programme metadata
* [x] Player programme display
* [x] Programme end-time storage
* [x] Initial startup cache implementation
* [x] Git milestone tagged (`v0.9.1`)

---

## v0.9.2 – BBC Metadata and HTTPS Stability

### BBC Metadata

* [x] Replace startup cache with on-demand metadata retrieval
* [x] Request metadata only for the selected BBC station
* [x] Delay metadata request until audio playback has started
* [x] Periodic programme metadata refresh
* [x] Active BBC metadata lifecycle management
* [x] Preserve commercial ICY metadata behaviour
* [x] Maintain audio processing during BBC HTTP requests

### Audio and Memory

* [x] Diagnose TLS failures as internal-memory pressure
* [x] Reduce I²S DMA descriptors from 32 to 16
* [x] Restore reliable HTTPS stream connections
* [x] Validate BBC metadata retrieval during active playback
* [x] Add heap diagnostics for metadata and audio testing

### Startup and Repository

* [x] Branded startup splash screen
* [x] Refined startup status sequence
* [x] Package project branding assets
* [x] Package Icon Builder and generated icon assets
* [x] Merge completed milestone into `main`
* [x] Git milestone tagged (`v0.9.2`)

## v0.9.3 – Product Polish

### User Interface

* [x] Review Player layout across representative stations
* [x] Final typography review
* [x] Review alignment, spacing and visual consistency
* [x] Review touch feedback and pressed-state consistency
* [x] Replace remaining hard-coded pressed-state colours with semantic theme colours
* [x] Review screen transitions and redraw behaviour
* [x] Wi-Fi configuration

### System

* [x] Reduce remaining development Serial output
* [x] Retain useful fault and startup diagnostics
* [x] Remove obsolete code and superseded metadata-cache logic
* [x] Final code organisation review
* [x] Documentation review

### Repository

* [x] Review packaged tools for setup instructions
* [x] Review tracked assets for completeness

---

---

## v0.9.4 – Hardware Integration

### Hardware

* Custom carrier PCB designed in KiCad
* ESP32-S3 and dual MAX98357A amplifier modules integrated
* External USB-C power and firmware-upload connection
* Rear-panel power switching
* PCB manufactured and assembled
* Complete hardware validated in the finished unit

### Enclosure

* Three-part enclosure designed for 3D printing
* Separate base, main chassis and face frame
* Dual 2" speaker mounting
* M3 threaded-insert construction
* Rear USB-C and power-button access
* Finished enclosure printed, assembled and validated

### Status

PASS — Custom hardware and enclosure completed.

---

## v1.0.0 – Internet Radio

### Release Milestone

* Firmware feature set completed
* User interface and Player experience completed
* Curated UK station library completed
* BBC and commercial-station metadata operational
* Dual-mono audio system completed
* Custom PCB and enclosure completed
* Final radio assembled and operational
* Build and deployment workflow validated
* Project documentation consolidated
* Git milestone tagged (`v1.0.0`)

### Public Release Preparation

Following completion of v1.0.0, the private development repository was reviewed and consolidated in preparation for a clean public release.

This included:

* Reviewing and consolidating project documentation
* Removing obsolete development notes and diagnostic material
* Reviewing build and deployment instructions
* Reviewing packaged tools and assets
* Preparing the project for publication from a clean repository snapshot

### Status

PASS — Internet Radio v1.0.0 completed and validated.

---

## v1.0.1 – Reliability and Usability Refinement

### Wi-Fi

* Added storage for up to three Wi-Fi networks
* Added visible-network scanning at startup
* Saved networks are attempted in most-recently-used order
* Reduced connection delay when moving between known networks
* Wi-Fi reset now clears both WiFiManager credentials and the saved network list

### Station Catalogue and Streaming

* Changed the All-stations catalogue to load in pages of up to five stations
* Reduced internal heap usage and fragmentation during station browsing
* Improved reliability when connecting to HTTPS/TLS audio streams
* Refreshed the curated station catalogue
* Removed the obsolete talkSPORT 2 stream

### Player

* Refined Player metadata layout and clearing behaviour
* Improved handling of longer artist and track information
* Added automatic return to the Player after 20 seconds of touchscreen inactivity while playback remains active
* Preserved current commercial-station metadata when returning to the Player
* Preserved BBC programme metadata when returning to the Player

### Maintenance

* Removed obsolete RadioBrowser test and debug modules
* Renumbered firmware modules while preserving compilation order
* Retained useful heap, catalogue and audio connection diagnostics
* Corrected display hardware documentation
* Updated Wi-Fi, Player and typography documentation

### Status

PASS — v1.0.1 firmware refinements implemented, compiled and validated on the completed radio.

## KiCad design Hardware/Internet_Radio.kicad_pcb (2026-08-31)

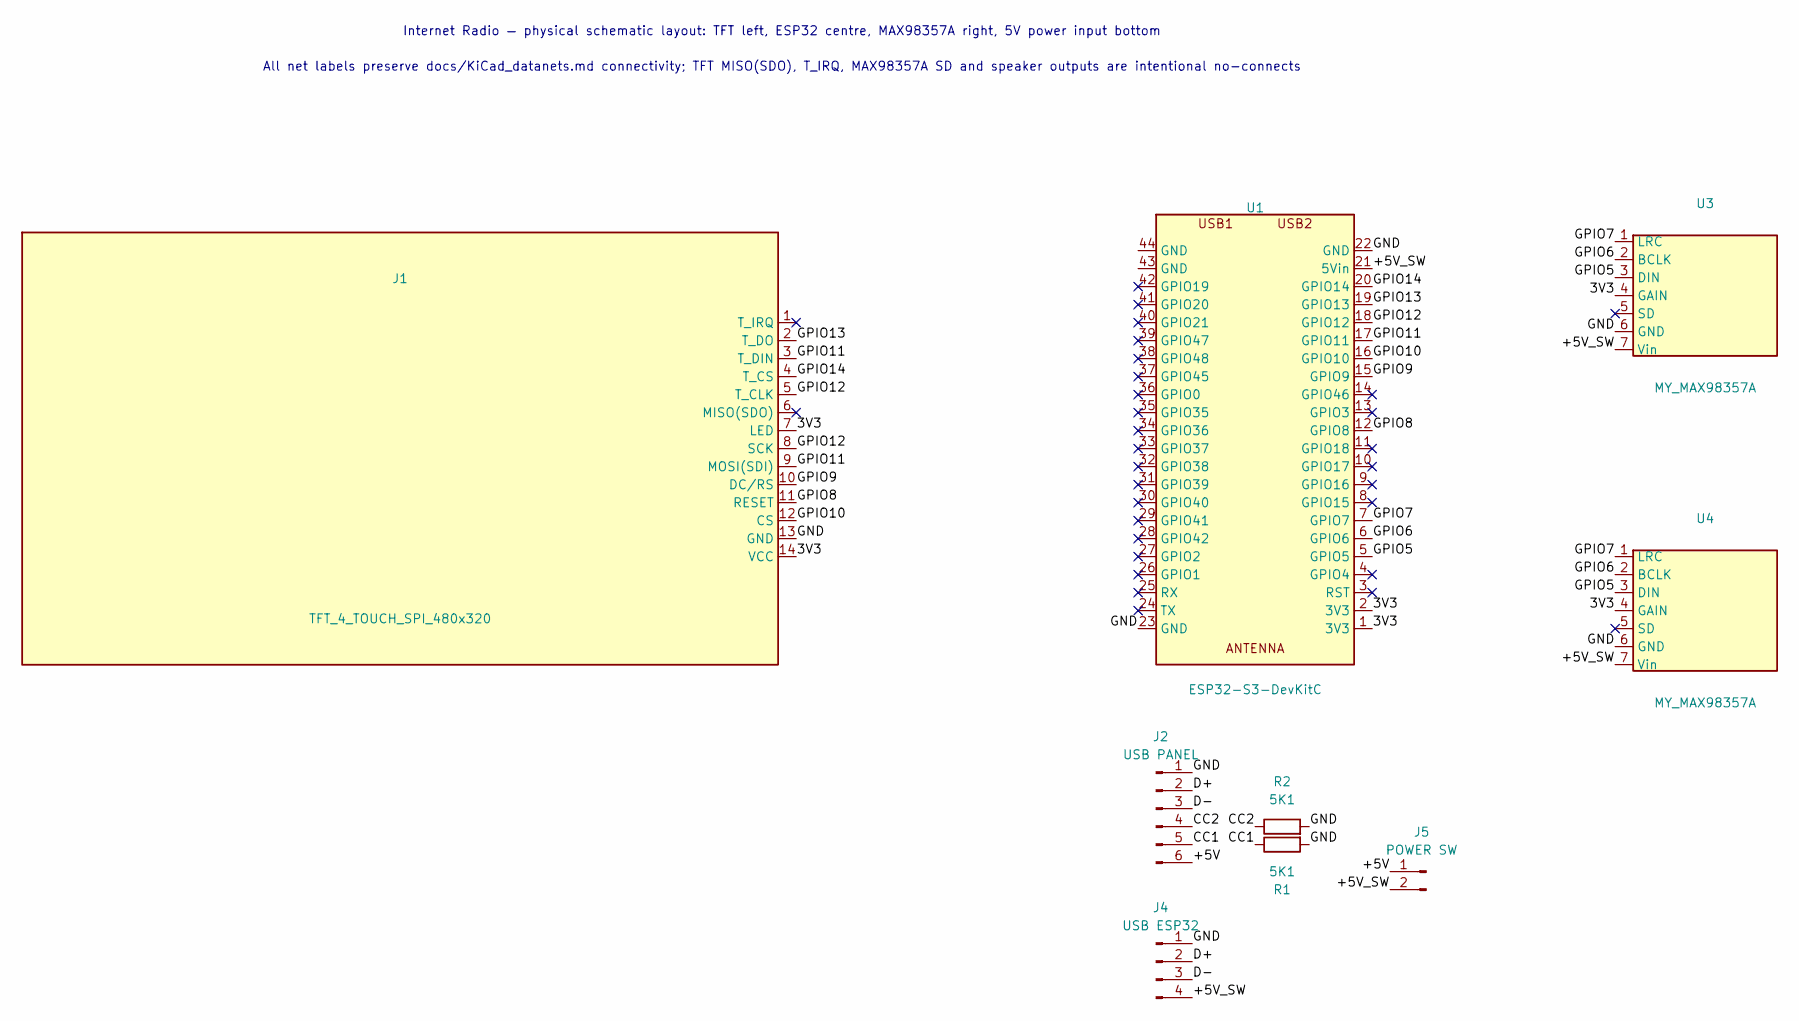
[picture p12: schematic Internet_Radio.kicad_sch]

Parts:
J1: TFT_4_TOUCH_SPI_480x320; TFT_4_TOUCH_SPI_480x320_PNG
J2: USB PANEL; JST_PH_B6B-PH-K_1x06_P2.00mm_Vertical
J4: USB ESP32; JST_XH_B4B-XH-A_1x04_P2.50mm_Vertical
J5: POWER SW; JST_XH_B2B-XH-A_1x02_P2.50mm_Vertical
R1, R2: 5K1; R_0603_1608Metric
U1: ESP32-S3-DevKitC; ESP32-S3-DevKitC_PNG
U3, U4: MY_MAX98357A; MY_MAX98357A_PNG

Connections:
/3V3: J1.7 (LED), J1.14 (VCC), U1.1 (3V3), U1.2 (3V3), U3.4 (GAIN), U4.4 (GAIN)
/+5V: J2.6, J5.1
/+5V_SW: J4.4, J5.2, U1.21 (5Vin), U3.7 (Vin), U4.7 (Vin)
/CC1: J2.5, R1.1
/CC2: J2.4, R2.1
/D+: J2.2, J4.2
/D-: J2.3, J4.3
/GND: J1.13 (GND), J2.1, J4.1, R1.2, R2.2, U1.22 (GND), U1.23 (GND), U3.6 (GND), U4.6 (GND)
/GPIO5: U1.5 (GPIO5), U3.3 (DIN), U4.3 (DIN)
/GPIO6: U1.6 (GPIO6), U3.2 (BCLK), U4.2 (BCLK)
/GPIO7: U1.7 (GPIO7), U3.1 (LRC), U4.1 (LRC)
/GPIO8: J1.11 (RESET), U1.12 (GPIO8)
/GPIO9: J1.10 (DC/RS), U1.15 (GPIO9)
/GPIO10: J1.12 (CS), U1.16 (GPIO10)
/GPIO11: J1.3 (T_DIN), J1.9 (MOSI(SDI)), U1.17 (GPIO11)
/GPIO12: J1.5 (T_CLK), J1.8 (SCK), U1.18 (GPIO12)
/GPIO13: J1.2 (T_DO), U1.19 (GPIO13)
/GPIO14: J1.4 (T_CS), U1.20 (GPIO14)

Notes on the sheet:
All net labels preserve docs/KiCad_datanets.md connectivity; TFT MISO(SDO), T_IRQ, MAX98357A SD and speaker outputs are intentional no-connects
Internet Radio — physical schematic layout: TFT left, ESP32 centre, MAX98357A right, 5V power input bottom

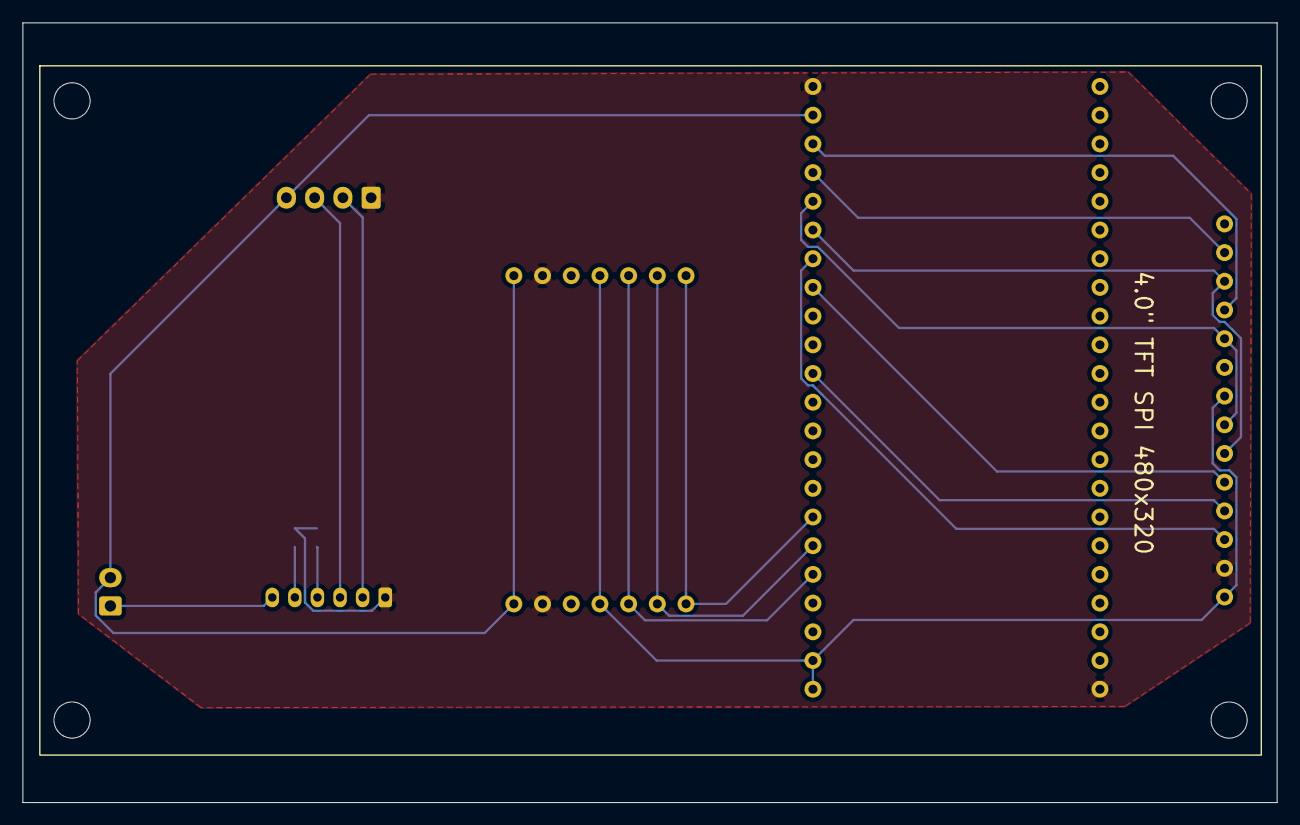
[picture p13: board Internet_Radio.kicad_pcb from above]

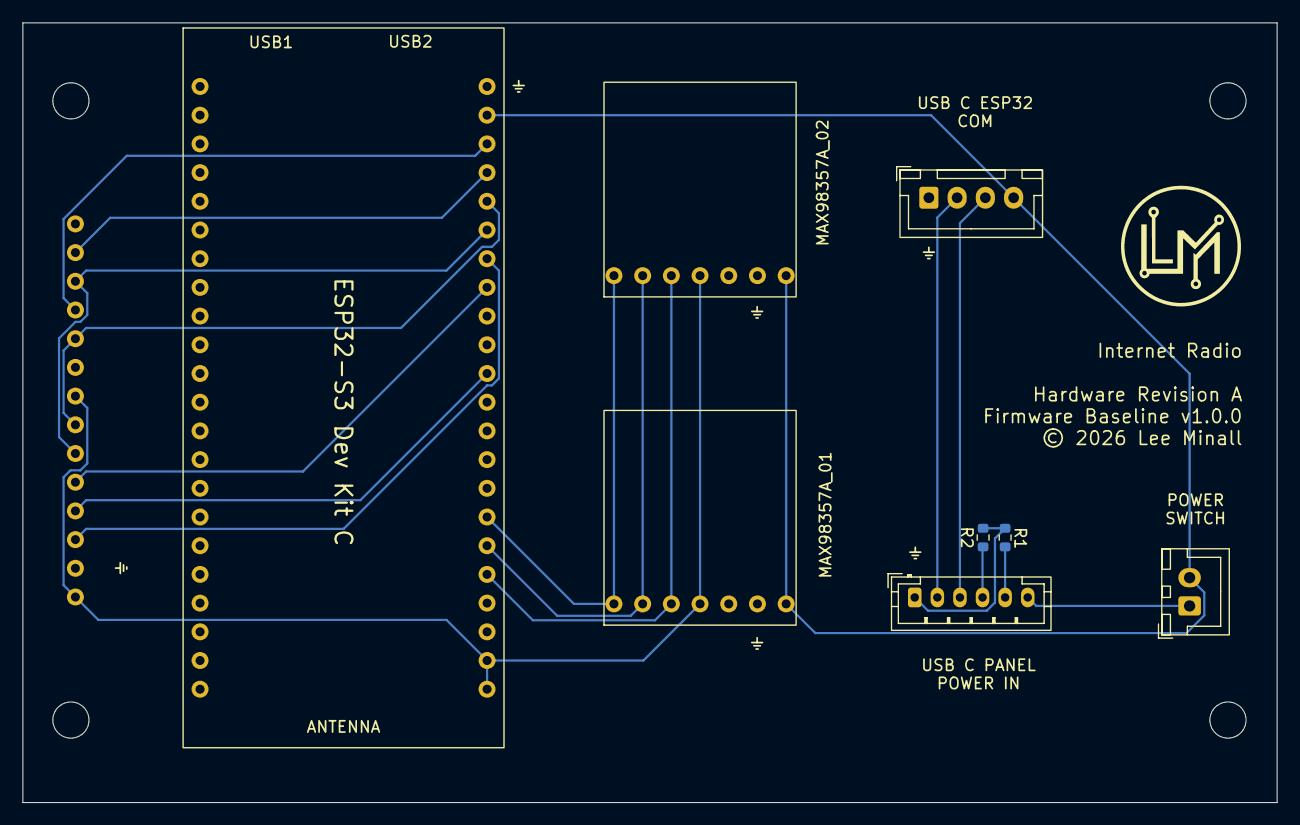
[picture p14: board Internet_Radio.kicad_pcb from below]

Board: 2 copper layers, 111.0 x 69.0 mm, 9 parts (8 on the bottom side), 18 nets.

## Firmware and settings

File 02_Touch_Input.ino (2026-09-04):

// ============================================================
// 02_Touch_Input.ino
// Touch Input Handling
// ============================================================
//
// Purpose:
//
// Reads the XPT2046 touch controller and converts touch events
// into application input.
//
// Responsibilities:
//
//   • Read touch coordinates.
//   • Apply screen calibration.
//   • Detect button presses.
//   • Route touch input to the active screen.
//
// This module contains touch input only. It does not draw the UI.
//
// ============================================================

bool splashAwaitingTouch = true;

// ============================================================
// Station Selection Helper
// ============================================================

void selectStationFromFooter(int footerButtonNumber) {
  int selectedIndex =
    stationPageStart + (footerButtonNumber - 1);

  if (selectedIndex >= stationCount) {
    Serial.println(
      "Footer station button ignored: no station on this button"
    );
    return;
  }

  selectedStationIndex = selectedIndex;

  Serial.println("Station selected from footer:");

  Serial.print("Index: ");
  Serial.println(selectedStationIndex);

  Serial.print("Name: ");
  Serial.println(stations[selectedStationIndex].name);

  Serial.print("URL: ");
  Serial.println(stations[selectedStationIndex].streamUrl);

  showMessage(
    stations[selectedStationIndex].name.c_str()
  );

  drawPlayerScreen();

  audioPlay(
    stations[selectedStationIndex].streamUrl
  );

  if (
    stations[selectedStationIndex].metadataService.length() > 0
  ) {
    bbcMetadataBegin(
      stations[selectedStationIndex].metadataService
    );
  } else {
    bbcMetadataStop();
  }
}


// ============================================================
// Screen Navigation Helper
// ============================================================

void navigateBack() {
  if (currentScreen == SCREEN_PLAYER) {
    drawStationsScreen();
    return;
  }

  if (currentScreen == SCREEN_STATIONS) {
    drawFilterScreen();
    return;
  }

  if (currentScreen == SCREEN_FILTERS) {
    drawHomeScreen();
    return;
  }

  drawHomeScreen();
}


// ============================================================
// Settings Modal
// ============================================================

void showSettingsModal() {
  Serial.println("Settings modal placeholder");

  safeTftStart();

  int modalX = 60;
  int modalY = 80;
  int modalW = 360;
  int modalH = 150;

  tft.fillRoundRect(
    modalX,
    modalY,
    modalW,
    modalH,
    12,
    theme.panel
  );

  tft.drawRoundRect(
    modalX,
    modalY,
    modalW,
    modalH,
    12,
    theme.buttonBorder
  );

  tft.setTextColor(
    theme.textPrimary,
    theme.panel
  );

  tft.setTextSize(3);
  tft.setCursor(
    modalX + 85,
    modalY + 35
  );

  tft.print("Settings");

  tft.setTextColor(
    theme.accent,
    theme.panel
  );

  tft.setTextSize(2);
  tft.setCursor(
    modalX + 75,
    modalY + 90
  );

  tft.print("Coming soon");

  safeTftEnd();
}

// ============================================================
// Home Screen Touch Handler
// ============================================================

bool handleHomeScreenTouch(int screenX, int screenY) {

  // Open station filter screen
  if (insideButton(
        screenX,
        screenY,
        stationsButton
      )) {

    drawButton(stationsButton, true);
    delay(150);
    drawButton(stationsButton, false);

    drawFilterScreen();
    return true;
  }

  // WiFi reset / setup
  if (insideButton(
        screenX,
        screenY,
        wifiSetupButton
      )) {

    if (!confirmWiFiReset) {
      confirmWiFiReset = true;
      confirmWiFiResetStart = millis();

      handleButtonPress(
        wifiSetupButton,
        "Press again to reset"
      );
    }
    else {
      confirmWiFiReset = false;

      handleButtonPress(
        wifiSetupButton,
        "Reset WiFi"
      );

      resetWiFiSettings();
    }

    return true;
  }

  return false;
}

// ============================================================
// Filter Screen Touch Handler
// ============================================================

bool handleFilterScreenTouch(int screenX, int screenY) {

  // ----------------------------------------------------------
  // Settings Button
  // ----------------------------------------------------------

  if (insideButton(
        screenX,
        screenY,
        filterSettingsButton
      )) {

    drawFilterSettingsButton(true);
    delay(150);
    drawFilterSettingsButton(false);

    drawHomeScreen();

    return true;
  }

  // ----------------------------------------------------------
  // Filter Selection
  // ----------------------------------------------------------

  int selectedFilter = -1;
  Button selectedButton;

  if (insideButton(
        screenX,
        screenY,
        filterBBCButton
      )) {

    selectedFilter = 0;
    selectedButton = filterBBCButton;
  }

  else if (insideButton(
             screenX,
             screenY,
             filterAbsoluteButton
           )) {

    selectedFilter = 1;
    selectedButton = filterAbsoluteButton;
  }

  else if (insideButton(
             screenX,
             screenY,
             filterVirginButton
           )) {

    selectedFilter = 2;
    selectedButton = filterVirginButton;
  }

  else if (insideButton(
             screenX,
             screenY,
             filterCapitalButton
           )) {

    selectedFilter = 3;
    selectedButton = filterCapitalButton;
  }

  else if (insideButton(
             screenX,
             screenY,
             filterHeartButton
           )) {

    selectedFilter = 4;
    selectedButton = filterHeartButton;
  }

  else if (insideButton(
             screenX,
             screenY,
             filterKissButton
           )) {

    selectedFilter = 5;
    selectedButton = filterKissButton;
  }

  else if (insideButton(
             screenX,
             screenY,
             filterRockButton
           )) {

    selectedFilter = 6;
    selectedButton = filterRockButton;
  }

  else if (insideButton(
             screenX,
             screenY,
             filterTalkButton
           )) {

    selectedFilter = 7;
    selectedButton = filterTalkButton;
  }

  else if (insideButton(
             screenX,
             screenY,
             filterAllButton
           )) {

    selectedFilter = 8;
    selectedButton = filterAllButton;
  }

  if (selectedFilter < 0) {
    return false;
  }

  drawFilterChoiceButton(
    selectedButton,
    true
  );

  delay(150);

  currentStationFilter = selectedFilter;
  stationPageStart = 0;

  if (!stationProviderLoad(
        stationFilters[currentStationFilter]
      )) {

    showMessage("Catalogue load failed");
    return true;
  }

  drawStationsScreen();

  return true;
}

// ============================================================
// Station List Screen Touch Handler
// ============================================================

bool handleStationListTouch(int screenX, int screenY) {

  // Return to Filter screen
  if (insideButton(
        screenX,
        screenY,
        filterMenuButton
      )) {

    drawFilterMenuButton(true);
    delay(150);
    drawFilterMenuButton(false);

    drawFilterScreen();
    return true;
  }

  // Footer Back button
  if (insideButton(
        screenX,
        screenY,
        backFooterButton
      )) {

    drawFooterBackButton(true);
    delay(150);
    drawFooterBackButton(false);

    navigateBack();
    return true;
  }

  // Footer Settings button
  if (insideButton(
        screenX,
        screenY,
        settingsFooterButton
      )) {

    drawFooterSettingsButton(true);
    delay(150);
    drawFooterSettingsButton(false);

    drawHomeScreen();

    return true;
  }

  // Previous station page
  if (insideButton(
        screenX,
        screenY,
        stationPrevButton
      )) {

    drawArrowButton(
      stationPrevButton,
      true,
      true
    );

    delay(150);

    drawArrowButton(
      stationPrevButton,
      false,
      true
    );

    if (currentStationFilter == 8) {

      int previousPage = allCataloguePage - 1;

      if (previousPage < 0) {
        previousPage = ALL_CATALOGUE_PAGE_COUNT - 1;
      }

      stationProviderLoadAllPage(previousPage);

    } else {

      stationPageStart -= STATIONS_PER_PAGE;

      if (stationPageStart < 0) {
        int lastPageStart =
          ((stationCount - 1) /
          STATIONS_PER_PAGE) *
          STATIONS_PER_PAGE;

        stationPageStart = lastPageStart;
      }

    }

    drawStationsScreen();
    return true;
  }

  // Next station page
  if (insideButton(
        screenX,
        screenY,
        stationNextButton
      )) {

    drawArrowButton(
      stationNextButton,
      true,
      false
    );

    delay(150);

    drawArrowButton(
      stationNextButton,
      false,
      false
    );

    if (currentStationFilter == 8) {

      int nextPage = allCataloguePage + 1;

      if (nextPage >= ALL_CATALOGUE_PAGE_COUNT) {
        nextPage = 0;
      }

      stationProviderLoadAllPage(nextPage);

    } else {

      stationPageStart += STATIONS_PER_PAGE;

      if (stationPageStart >= stationCount) {
        stationPageStart = 0;
      }

    }

    drawStationsScreen();
    return true;
  }

  // Station selection buttons
  if (insideButton(
        screenX,
        screenY,
        stationSelectButton1
      )) {

    selectStationFromFooter(1);
    return true;
  }

  if (insideButton(
        screenX,
        screenY,
        stationSelectButton2
      )) {

    selectStationFromFooter(2);
    return true;
  }

  if (insideButton(
        screenX,
        screenY,
        stationSelectButton3
      )) {

    selectStationFromFooter(3);
    return true;
  }

  if (insideButton(
        screenX,
        screenY,
        stationSelectButton4
      )) {

    selectStationFromFooter(4);
    return true;
  }

  if (insideButton(
        screenX,
        screenY,
        stationSelectButton5
      )) {

    selectStationFromFooter(5);
    return true;
  }

  return false;
}

// ============================================================
// Player Screen Touch Handler
// ============================================================

bool handlePlayerScreenTouch(int screenX, int screenY) {
  static int volumeBeforeMute = 14;
  static bool playerMuted = false;

  // Return to Station List while playback continues
  if (insideButton(
        screenX,
        screenY,
        playerBackButton
      )) {

    drawPlayerSymbolButton(
      playerBackButton,
      theme.playerBack,
      true,
      PLAYER_SYMBOL_BACK
    );

    delay(150);

    navigateBack();

    return true;
  }

  // Stop playback and return to Filter screen
  if (insideButton(
        screenX,
        screenY,
        playerStopButton
      )) {

    drawPlayerSymbolButton(
      playerStopButton,
      theme.playerStop,
      true,
      PLAYER_SYMBOL_STOP
    );

    delay(150);

    audioStop();

    drawFilterScreen();

    return true;
  }

  // Volume down
  if (insideButton(
        screenX,
        screenY,
        playerVolumeDownButton
      )) {

    int newVolume =
      constrain(audioGetVolume() - 1, 0, 21);

    audioSetVolume(newVolume);

    playerMuted = false;

    drawPlayerSymbolButton(
      playerVolumeDownButton,
      theme.playerVolumeDown,
      true,
      PLAYER_SYMBOL_DOWN
    );

    delay(150);

    drawPlayerSymbolButton(
      playerVolumeDownButton,
      theme.playerVolumeDown,
      false,
      PLAYER_SYMBOL_DOWN
    );

    return true;
  }

  // Mute / restore volume
  if (insideButton(
        screenX,
        screenY,
        playerMuteButton
      )) {

    if (!playerMuted) {
      volumeBeforeMute = audioGetVolume();
      audioSetVolume(0);
      playerMuted = true;
    }
    else {
      audioSetVolume(volumeBeforeMute);
      playerMuted = false;
    }

    drawPlayerControlButton(
      playerMuteButton,
      "MUTE",
      theme.playerMute,
      playerMuted
    );

    return true;
  }

  // Volume up
  if (insideButton(
        screenX,
        screenY,
        playerVolumeUpButton
      )) {

    int newVolume =
      constrain(audioGetVolume() + 1, 0, 21);

    audioSetVolume(newVolume);

    playerMuted = false;

    drawPlayerSymbolButton(
      playerVolumeUpButton,
      theme.playerVolumeUp,
      true,
      PLAYER_SYMBOL_UP
    );

    delay(150);

    drawPlayerSymbolButton(
      playerVolumeUpButton,
      theme.playerVolumeUp,
      false,
      PLAYER_SYMBOL_UP
    );

    return true;
  }

  return false;
}


// ============================================================
// Main Loop / Touch Dispatcher
// ============================================================

void loop() {

  // ----------------------------------------------------------
  // Audio Engine
  // ----------------------------------------------------------

  audioLoop();

  // ----------------------------------------------------------
  // Player Metadata Update
  // ----------------------------------------------------------

  bbcMetadataLoop();

  if (
    currentScreen == SCREEN_PLAYER &&
    (
      streamTitleChanged ||
      bbcMetadataChanged
    )
  ) {
    drawPlayerMetadataArea();

    streamTitleChanged = false;
    bbcMetadataChanged = false;
  }

  // ----------------------------------------------------------
  // Touch Input
  // ----------------------------------------------------------

  if (ts.touched()) {

    lastUserInteraction = millis();

    TS_Point p = ts.getPoint();

    int screenX =
      map(
        p.x,
        TOUCH_MIN_X,
        TOUCH_MAX_X,
        0,
        480
      );

    int screenY =
      map(
        p.y,
        TOUCH_MIN_Y,
        TOUCH_MAX_Y,
        0,
        320
      );

    screenX = constrain(
      screenX,
      0,
      479
    );

    screenY = constrain(
      screenY,
      0,
      319
    );

    Serial.print("Raw X=");
    Serial.print(p.x);
    Serial.print(" Y=");
    Serial.print(p.y);
    Serial.print(" -> Screen X=");
    Serial.print(screenX);
    Serial.print(" Y=");
    Serial.println(screenY);

    // --------------------------------------------------------
    // Splash Screen Touch Gate
    // --------------------------------------------------------

    if (splashAwaitingTouch) {

      splashAwaitingTouch = false;

      // Consume the complete touch before drawing the Home
      // screen, preventing the same press from activating an
      // underlying Home-screen control.
      while (ts.touched()) {
        audioLoop();
        delay(1);
      }

      drawFilterScreen();

      return;
    }

    // --------------------------------------------------------
    // Dispatch Touch According to Current Screen
    // --------------------------------------------------------

    switch (currentScreen) {

      // ------------------------------------------------------
      // Home Screen
      // ------------------------------------------------------

      case SCREEN_HOME:
        handleHomeScreenTouch(
          screenX,
          screenY
        );
        break;

      // ------------------------------------------------------
      // Filter Screen
      // ------------------------------------------------------

      case SCREEN_FILTERS:
        handleFilterScreenTouch(
          screenX,
          screenY
        );
        break;

      // ------------------------------------------------------
      // Station List Screen
      // ------------------------------------------------------

      case SCREEN_STATIONS:
        handleStationListTouch(
          screenX,
          screenY
        );
        break;

      // ------------------------------------------------------
      // Player Screen
      // ------------------------------------------------------

      case SCREEN_PLAYER:
        handlePlayerScreenTouch(
          screenX,
          screenY
        );
        break;
    }
  }

  // ----------------------------------------------------------
  // Deferred UI Messages
  // ----------------------------------------------------------

  if (messagePending) {

    showMessage(
      pendingMessage.c_str()
    );

    messagePending = false;
  }

  // ----------------------------------------------------------
  // WiFi Reset Confirmation Timeout
  // ----------------------------------------------------------

  if (
    confirmWiFiReset &&
    millis() - confirmWiFiResetStart > 5000
  ) {

    confirmWiFiReset = false;

    showMessage("Reset cancelled");
    delay(1000);

    String wifiStatus =
      WiFi.SSID() +
      " " +
      WiFi.localIP().toString();

    showMessage(
      wifiStatus.c_str()
    );
  }

  // ----------------------------------------------------------
  // Automatic Return to Player
  // ----------------------------------------------------------

  if (
    audioIsPlaying &&
    currentScreen != SCREEN_PLAYER &&
    millis() - lastUserInteraction >= PLAYER_RETURN_TIMEOUT_MS
  ) {

    drawPlayerScreen();

    lastUserInteraction = millis();
  }

  // ----------------------------------------------------------
  // Loop Throttle
  // ----------------------------------------------------------

  delay(1);
}

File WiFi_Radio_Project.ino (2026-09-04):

// ============================================================
// Internet Radio Project
// Main application entry point
// ============================================================
//
// Responsibilities:
//
//   • Include required libraries
//   • Define shared structures and global state
//   • Initialise display, touch, LittleFS, WiFi and typography
//   • Start the initial UI screen
//
// ============================================================

#include <WiFiManager.h>
#include <TFT_eSPI.h>
#include <XPT2046_Touchscreen.h>
#include <SPI.h>
#include <WiFi.h>
#include <WiFiClientSecure.h>
#include <HTTPClient.h>
#include <ArduinoJson.h>
#include <Preferences.h>
#include <LittleFS.h>
#include <PNGdec.h>

// ============================================================
// Display Hardware
// ============================================================

SPIClass touchSPI(HSPI);

#define TFT_CS_PIN 10
#define TOUCH_CS   14

#define TOUCH_MIN_X 300
#define TOUCH_MAX_X 3820
#define TOUCH_MIN_Y 420
#define TOUCH_MAX_Y 3770

TFT_eSPI tft = TFT_eSPI();
XPT2046_Touchscreen ts(TOUCH_CS);

// ============================================================
// Audio Hardware
// ============================================================

#define I2S_BCLK  6
#define I2S_LRCK  7
#define I2S_DOUT  5

// ============================================================
// Shared UI Structures
// ============================================================

struct Button {
  int x;
  int y;
  int w;
  int h;
  const char* label;
};

enum PlayerSymbol {
  PLAYER_SYMBOL_BACK,
  PLAYER_SYMBOL_STOP,
  PLAYER_SYMBOL_DOWN,
  PLAYER_SYMBOL_UP
};

struct UITheme {
  uint16_t bg;
  uint16_t panel;
  uint16_t headerBg;
  uint16_t footerBg;

  uint16_t textPrimary;
  uint16_t textSecondary;
  uint16_t textMuted;
  uint16_t textValue;
  uint16_t textStrong;

  uint16_t accent;
  uint16_t buttonBg;
  uint16_t playerButtonBg;
  uint16_t buttonBorder;
  uint16_t buttonText;

  uint16_t wifiGood;
  uint16_t wifiWeak;
  uint16_t wifiOff;

  uint16_t playerBack;
  uint16_t playerStop;
  uint16_t playerVolumeDown;
  uint16_t playerMute;
  uint16_t playerVolumeUp;
};

extern UITheme theme;

// ============================================================
// Theme IDs
// ============================================================

enum ThemeID {
  THEME_MIDNIGHT,
  THEME_GRAPHITE,
  THEME_OCEAN,
  THEME_AMBER,
  THEME_RETRO_GREEN,
  THEME_DAYLIGHT,
  THEME_COUNT
};

const char* const themeNames[THEME_COUNT] = {
  "Midnight",
  "Graphite",
  "Ocean",
  "Amber",
  "Retro Green",
  "Daylight"
};

// ============================================================
// Screen / Typography IDs
// ============================================================

enum ScreenMode {
  SCREEN_HOME,
  SCREEN_STATIONS,
  SCREEN_FILTERS,
  SCREEN_PLAYER
};

enum UITypeStyle {
  TYPE_DISPLAY,
  TYPE_HEADER,
  TYPE_SECTION,
  TYPE_BODY,
  TYPE_BUTTON,
  TYPE_CAPTION,
  TYPE_STATUS
};

// ============================================================
// Icon IDs
// ============================================================

enum IconId {
  ICON_WIFI_ON,
  ICON_WIFI_OFF,

  ICON_CATALOGUE,
  ICON_STATIONS,

  ICON_ROUTER_ON,
  ICON_ROUTER_OFF,

  ICON_BACK,
  ICON_SETTINGS
};

enum IconSize {
  ICON_SMALL,   // 24
  ICON_MEDIUM,  // 32
  ICON_LARGE    // 48
};

// ============================================================
// Runtime UI State
// ============================================================

ScreenMode currentScreen = SCREEN_HOME;

bool audioIsPlaying = false;

unsigned long lastUserInteraction = 0;
const unsigned long PLAYER_RETURN_TIMEOUT_MS = 20000;

String headerTitle  = "";
String headerCentre = "";
uint8_t headerStatus = 0;
int allCataloguePage = 0;
const int ALL_CATALOGUE_PAGE_COUNT = 14;

// ============================================================
// Header Status Icons
// ============================================================

const uint8_t HEADER_STATUS_NONE = 0;
const uint8_t HEADER_STATUS_WIFI = 1;

// ============================================================
// Buttons
// ============================================================

Button backFooterButton     = {10, 255, 45, 45, ""};

Button stationSelectButton1 = {68, 255, 60, 45, "1"};
Button stationSelectButton2 = {138, 255, 60, 45, "2"};
Button stationSelectButton3 = {208, 255, 60, 45, "3"};
Button stationSelectButton4 = {278, 255, 60, 45, "4"};
Button stationSelectButton5 = {348, 255, 60, 45, "5"};

Button settingsFooterButton = {425, 255, 45, 45, ""};

Button stationsButton       = {25, 245, 200, 55, "Filter"};
Button wifiSetupButton      = {255, 245, 200, 55, "WiFi"};

Button filterMenuButton     = {25, 10, 180, 52, ""};

Button filterBBCButton      = {25, 55, 135, 60, "BBC"};
Button filterAbsoluteButton = {172, 55, 135, 60, "Absolute"};
Button filterVirginButton   = {319, 55, 135, 60, "Virgin"};

Button filterCapitalButton  = {25, 125, 135, 60, "Capital"};
Button filterHeartButton    = {172, 125, 135, 60, "Heart"};
Button filterKissButton     = {319, 125, 135, 60, "Kiss"};

Button filterRockButton     = {25, 193, 135, 60, "Rock"};
Button filterTalkButton     = {172, 193, 135, 60, "Talk"};
Button filterAllButton      = {319, 193, 135, 60, "All"};

Button filterSettingsButton = {110, 266, 260, 40, "Settings"};

Button stationPrevButton    = {425, 70, 45, 73, "^"};
Button stationNextButton    = {425, 152, 45, 73, "v"};

// ============================================================
// Player Footer Buttons
// ============================================================

Button playerBackButton       = { 10, 265, 88, 45, "" };
Button playerStopButton       = {103, 265, 88, 45, ""};
Button playerVolumeDownButton = {196, 265, 88, 45, ""};
Button playerMuteButton       = {289, 265, 88, 45, ""};
Button playerVolumeUpButton   = {382, 265, 88, 45, ""};

// ============================================================
// Message State
// ============================================================

String pendingMessage = "";
bool messagePending = false;

// ============================================================
// Station Data
// ============================================================

const int MAX_STATIONS = 80;
const int STATIONS_PER_PAGE = 5;

struct Station {
  String name;
  String streamUrl;
  String resolvedUrl;
  String homepage;
  String metadataService;
  String favicon;
  String logo;
  String tags;
  String codec;
  int bitrate;
  bool isHLS;
};

Station stations[MAX_STATIONS];
int stationCount = 0;
int stationPageStart = 0;
int selectedStationIndex = -1;

// ============================================================
// Station Filters
// ============================================================

const char* stationFilters[] = {
  "BBC",
  "Absolute",
  "Virgin",
  "Capital",
  "Heart",
  "Kiss",
  "Rock",
  "Talk",
  "All"
};

const int stationFilterCount = 9;
int currentStationFilter = 0;
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

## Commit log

2026-08-31 Initial public release of Wi-Fi Radio Project
    [IRP_BOM.csv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]
2026-09-01 Add project publication links and fix BOM formatting

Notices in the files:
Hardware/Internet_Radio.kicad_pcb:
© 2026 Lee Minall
